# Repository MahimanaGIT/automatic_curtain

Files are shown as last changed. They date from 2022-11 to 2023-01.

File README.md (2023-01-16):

<h1 align="center">Automatic Curtain</h1>

<div align="center">
Elevate your home with IoT-enabled smart curtain controller for effortless living
</div>

## ⭐️ Why Automatic Curtain?
Automating blinds can provide convenience and energy efficiency. They can be programmed to open and close at specific times of the day, allowing natural light in to reduce the need of artificial lighting. They can also be controlled remotely, making it easy to adjust the amount of light and privacy in a room without having to physically adjust the blinds. Additionally, automatic blinds can help to regulate the temperature in a room.

## 🔥 Watch the video

<p align="center">
  <a href="https://www.youtube.com/watch?v=RMJ6SqKFGqU">
    Video
  </a>
</p>

## ✨ Features

- 😎 Easy to set up and integrate
- 📱 Remote control - the ability to open and close the curtains with precision using Alexa app
- 🛡 Safety feature - the ability to detect obstacles and stop the motor to prevent injury or damage to the curtains
- 💅 Manual Override - the ability to manually operate the curtains in case of Alexa not available
- 🚀 Motorized operation - the ability to open and close the curtains using a motor, rather than manual operation
- 📦 Smart home integration - the ability to connect the blinds to other smart home devices such as thermostat using alexa. Provides added convenience and energy efficiency

## 📋 [Doxygen Documentation](https://mahimanagit.github.io/automatic_curtain/)

## 🚀 Getting Started
### For how to use and build your own, refer [🗒 Manual](resources/MANUAL/manual.pdf)
### 👨‍💻 [Coding Style](https://google.github.io/styleguide/cppguide.html)
### Steps to setup for development:
1. Clone the repo
2. Setup clang format:
   - Install clang format extension in VS Code: 
    ```
      Name: Clang-Format
      Id: xaver.clang-format
      Description: Use Clang-Format in Visual Studio Code
      Version: 1.9.0
      Publisher: xaver
      VS Marketplace Link: https://marketplace.visualstudio.com/items?itemName=xaver.clang-format
    ```
   - Add following lines to **settings.json** in your VS Code:
    ```
    "editor.formatOnSave": true
    ```
    Now, everytime you save your code will automatically be formatted according to clang
    
3. Setup ESP32 Arduino Core using [this guide](https://randomnerdtutorials.com/installing-the-esp32-board-in-arduino-ide-windows-instructions/)
   
4. Setup Libraries
   - The link to all the libraries can be found at the end of this page. A compressed folder of all the libraries can be found in the [folder](resources/LIBRARY_ZIP/ac_lib.zip)
   - You can download the libraries using the links or just copy the extracted libraries from the above compressed folder in the **~/Arduino/libraries** or your customized library folder.

### Optional setup for development:
1. Setup doxygen:
   - Install doxygen and graphviz (doxygen uses dot from graphviz to generate graphs):
      ```
      sudo apt-get install doxygen
      sudo apt-get install graphviz 
      ```
   - Currently, the **DOT_PATH** is hardcoded in **Doxyfile** as `/usr/bin/dot` on line no. 2398, one can check if the dot path in their system is same or not by running
      ```
      which dot
      ```
      If the path is different, update it in the doxyfile
   - Generate doxygen files by running the following command in the terminal:
      ```
      doxygen Doxyfile
      ```
    - The files will be available in `doxygen` folder, click on or open `index.html` in **html** folder with any browser and you would be able to browse the documentation

## 🛡️ License

Automatic Curtain is licensed under the MIT License - see the [LICENSE](LICENSE.md) file for details.

## 🗒 References:

Thanks to the following repos for making the journey easier for the project:

1. [AsyncTCP](https://github.com/me-no-dev/AsyncTCP.git)
2. [Fauxmo](https://github.com/vintlabs/fauxmoESP.git)
3. [ESPAsyncWebServer](https://github.com/me-no-dev/ESPAsyncWebServer.git)
4. [FastLED](https://github.com/FastLED/FastLED.git)
5. [TMCStepper](https://github.com/teemuatlut/TMCStepper.gi)

For awesome readme help, referenced [novu](https://github.com/novuhq/novu)

## ✏️ Contributors 

- Dhiraj Deshmukh (deshmukhdhiraj15@gmail.com)
- Mahimana Bhatt (mahimanabhatt@gmail.com)

## 💻 Need Help?

We are more than happy to help you. If you are getting any errors or facing problems while working on this project, join our [slack](https://join.slack.com/t/mad-myj2315/shared_invite/zt-1n3oqsv1z-pdAomyv074gVCvfYfFaRgA) and ask for help. We are open to discussing anything related to the project.

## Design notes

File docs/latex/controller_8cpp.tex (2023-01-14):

\hypertarget{controller_8cpp}{}\section{mvp/src/controller/controller.cpp File Reference}
\label{controller_8cpp}\index{mvp/src/controller/controller.\+cpp@{mvp/src/controller/controller.\+cpp}}

Contains algorithms which controls the whole device from initialization to giving commands to every subsystem.  

{\ttfamily \#include \char`\"{}controller.\+h\char`\"{}}\newline
{\ttfamily \#include $<$Arduino.\+h$>$}\newline
{\ttfamily \#include $<$stdio.\+h$>$}\newline
{\ttfamily \#include $<$stdlib.\+h$>$}\newline
{\ttfamily \#include $<$chrono$>$}\newline
{\ttfamily \#include $<$memory$>$}\newline
{\ttfamily \#include \char`\"{}../alexa\+\_\+interaction/alexa\+\_\+interaction.\+h\char`\"{}}\newline
{\ttfamily \#include \char`\"{}../config/config.\+h\char`\"{}}\newline
{\ttfamily \#include \char`\"{}../connectivity/connectivity.\+h\char`\"{}}\newline
{\ttfamily \#include \char`\"{}../indicator/indicator.\+h\char`\"{}}\newline
{\ttfamily \#include \char`\"{}../logging/logging.\+h\char`\"{}}\newline
{\ttfamily \#include \char`\"{}../manual\+\_\+interaction/manual\+\_\+interaction.\+h\char`\"{}}\newline
{\ttfamily \#include \char`\"{}../motor\+\_\+driver/motor\+\_\+driver.\+h\char`\"{}}\newline
{\ttfamily \#include \char`\"{}../storage/storage.\+h\char`\"{}}\newline
Include dependency graph for controller.\+cpp\+:
\nopagebreak
\begin{figure}[H]
\begin{center}
\leavevmode
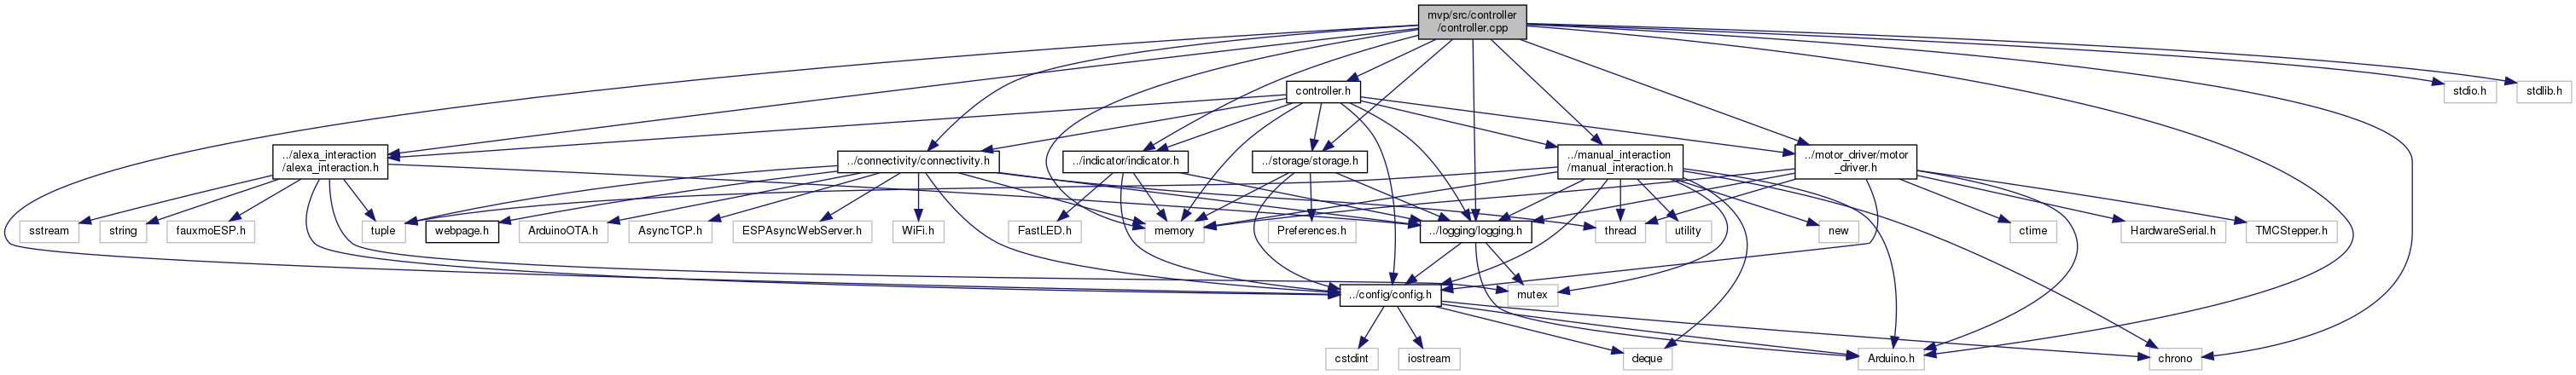
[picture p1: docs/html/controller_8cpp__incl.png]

\end{center}
\end{figure}

\subsection{Detailed Description}
Contains algorithms which controls the whole device from initialization to giving commands to every subsystem. 

\begin{DoxyAuthor}{Author}
Dhiraj Deshmukh (\href{mailto:deshmukhdhiraj15@gmail.com}{\tt deshmukhdhiraj15@gmail.\+com}) 
\end{DoxyAuthor}
\begin{DoxyVersion}{Version}
0.\+1 
\end{DoxyVersion}
\begin{DoxyDate}{Date}
2022-\/07-\/19
\end{DoxyDate}
\begin{DoxyCopyright}{Copyright}
Copyright (c) 2022 
\end{DoxyCopyright}

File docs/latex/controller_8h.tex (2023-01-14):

\hypertarget{controller_8h}{}\section{mvp/src/controller/controller.h File Reference}
\label{controller_8h}\index{mvp/src/controller/controller.\+h@{mvp/src/controller/controller.\+h}}

Defines the structure of the main controller of the device.  

{\ttfamily \#include $<$memory$>$}\newline
{\ttfamily \#include \char`\"{}../alexa\+\_\+interaction/alexa\+\_\+interaction.\+h\char`\"{}}\newline
{\ttfamily \#include \char`\"{}../config/config.\+h\char`\"{}}\newline
{\ttfamily \#include \char`\"{}../connectivity/connectivity.\+h\char`\"{}}\newline
{\ttfamily \#include \char`\"{}../indicator/indicator.\+h\char`\"{}}\newline
{\ttfamily \#include \char`\"{}../logging/logging.\+h\char`\"{}}\newline
{\ttfamily \#include \char`\"{}../manual\+\_\+interaction/manual\+\_\+interaction.\+h\char`\"{}}\newline
{\ttfamily \#include \char`\"{}../motor\+\_\+driver/motor\+\_\+driver.\+h\char`\"{}}\newline
{\ttfamily \#include \char`\"{}../storage/storage.\+h\char`\"{}}\newline
Include dependency graph for controller.\+h\+:
\nopagebreak
\begin{figure}[H]
\begin{center}
\leavevmode
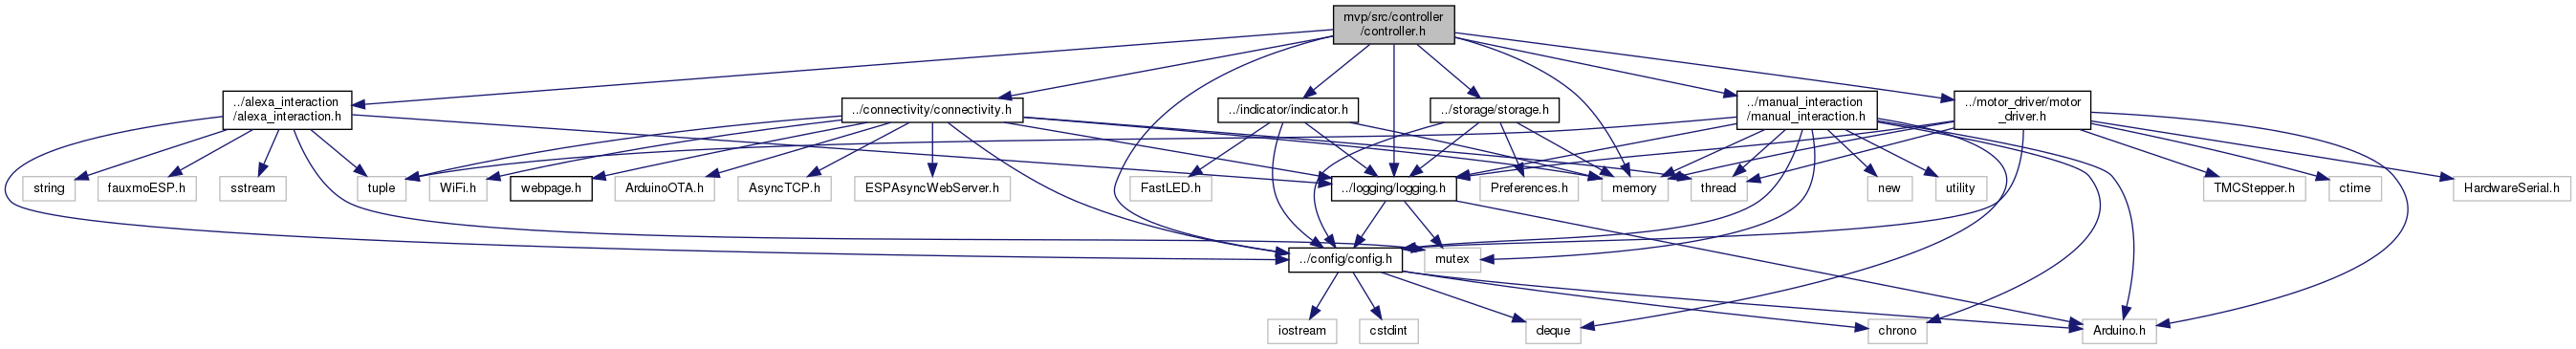
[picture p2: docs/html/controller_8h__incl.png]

\end{center}
\end{figure}
This graph shows which files directly or indirectly include this file\+:
\nopagebreak
\begin{figure}[H]
\begin{center}
\leavevmode
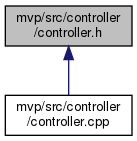
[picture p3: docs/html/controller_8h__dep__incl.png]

\end{center}
\end{figure}
\subsection*{Classes}
\begin{DoxyCompactItemize}
\item 
class \hyperlink{classController}{Controller}
\end{DoxyCompactItemize}

\subsection{Detailed Description}
Defines the structure of the main controller of the device. 

\begin{DoxyAuthor}{Author}
Mahimana Bhatt (\href{mailto:mahimanabhatt@gmail.com}{\tt mahimanabhatt@gmail.\+com}) 
\end{DoxyAuthor}
\begin{DoxyVersion}{Version}
0.\+1 
\end{DoxyVersion}
\begin{DoxyDate}{Date}
2022-\/07-\/19
\end{DoxyDate}
\begin{DoxyCopyright}{Copyright}
Copyright (c) 2022 
\end{DoxyCopyright}

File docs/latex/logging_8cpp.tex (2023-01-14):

\hypertarget{logging_8cpp}{}\section{mvp/src/logging/logging.cpp File Reference}
\label{logging_8cpp}\index{mvp/src/logging/logging.\+cpp@{mvp/src/logging/logging.\+cpp}}

Contains all algorithms for maintaing device logs.  

{\ttfamily \#include \char`\"{}logging.\+h\char`\"{}}\newline
{\ttfamily \#include $<$Arduino.\+h$>$}\newline
{\ttfamily \#include $<$mutex$>$}\newline
{\ttfamily \#include \char`\"{}../config/config.\+h\char`\"{}}\newline
Include dependency graph for logging.\+cpp\+:
\nopagebreak
\begin{figure}[H]
\begin{center}
\leavevmode
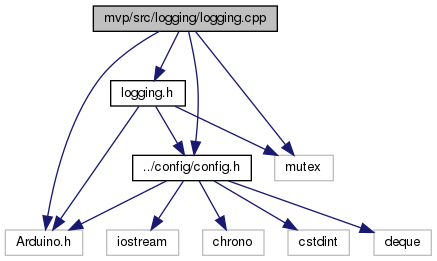
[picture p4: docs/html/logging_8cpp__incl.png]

\end{center}
\end{figure}

\subsection{Detailed Description}
Contains all algorithms for maintaing device logs. 

\begin{DoxyAuthor}{Author}
Dhiraj Deshmukh (\href{mailto:deshmukhdhiraj15@gmail.com}{\tt deshmukhdhiraj15@gmail.\+com}) 
\end{DoxyAuthor}
\begin{DoxyVersion}{Version}
0.\+1 
\end{DoxyVersion}
\begin{DoxyDate}{Date}
2022-\/07-\/19
\end{DoxyDate}
\begin{DoxyCopyright}{Copyright}
Copyright (c) 2022 
\end{DoxyCopyright}

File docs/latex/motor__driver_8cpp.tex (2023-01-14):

\hypertarget{motor__driver_8cpp}{}\section{mvp/src/motor\+\_\+driver/motor\+\_\+driver.cpp File Reference}
\label{motor__driver_8cpp}\index{mvp/src/motor\+\_\+driver/motor\+\_\+driver.\+cpp@{mvp/src/motor\+\_\+driver/motor\+\_\+driver.\+cpp}}

Contains algorithms for controlling stepper motor.  

{\ttfamily \#include \char`\"{}motor\+\_\+driver.\+h\char`\"{}}\newline
{\ttfamily \#include $<$Arduino.\+h$>$}\newline
{\ttfamily \#include $<$Hardware\+Serial.\+h$>$}\newline
{\ttfamily \#include $<$T\+M\+C\+Stepper.\+h$>$}\newline
{\ttfamily \#include $<$ctime$>$}\newline
{\ttfamily \#include \char`\"{}../config/config.\+h\char`\"{}}\newline
{\ttfamily \#include \char`\"{}../logging/logging.\+h\char`\"{}}\newline
Include dependency graph for motor\+\_\+driver.\+cpp\+:
\nopagebreak
\begin{figure}[H]
\begin{center}
\leavevmode
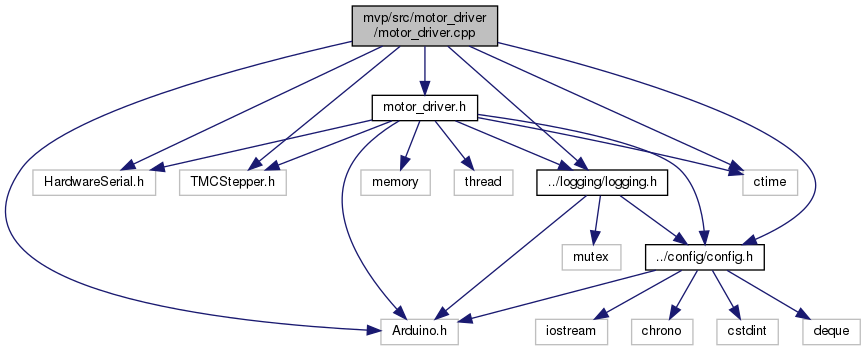
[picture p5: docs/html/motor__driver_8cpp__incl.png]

\end{center}
\end{figure}

\subsection{Detailed Description}
Contains algorithms for controlling stepper motor. 

\begin{DoxyAuthor}{Author}
Dhiraj Deshmukh (\href{mailto:deshmukhdhiraj15@gmail.com}{\tt deshmukhdhiraj15@gmail.\+com}) 
\end{DoxyAuthor}
\begin{DoxyVersion}{Version}
0.\+1 
\end{DoxyVersion}
\begin{DoxyDate}{Date}
2022-\/07-\/19
\end{DoxyDate}
\begin{DoxyCopyright}{Copyright}
Copyright (c) 2022 
\end{DoxyCopyright}

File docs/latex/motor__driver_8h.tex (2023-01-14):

\hypertarget{motor__driver_8h}{}\section{mvp/src/motor\+\_\+driver/motor\+\_\+driver.h File Reference}
\label{motor__driver_8h}\index{mvp/src/motor\+\_\+driver/motor\+\_\+driver.\+h@{mvp/src/motor\+\_\+driver/motor\+\_\+driver.\+h}}

Defines structure for controller of stepper motor, uses library T\+M\+C2209 for this usecase.  

{\ttfamily \#include $<$Arduino.\+h$>$}\newline
{\ttfamily \#include $<$Hardware\+Serial.\+h$>$}\newline
{\ttfamily \#include $<$T\+M\+C\+Stepper.\+h$>$}\newline
{\ttfamily \#include $<$ctime$>$}\newline
{\ttfamily \#include $<$memory$>$}\newline
{\ttfamily \#include $<$thread$>$}\newline
{\ttfamily \#include \char`\"{}../config/config.\+h\char`\"{}}\newline
{\ttfamily \#include \char`\"{}../logging/logging.\+h\char`\"{}}\newline
Include dependency graph for motor\+\_\+driver.\+h\+:
\nopagebreak
\begin{figure}[H]
\begin{center}
\leavevmode
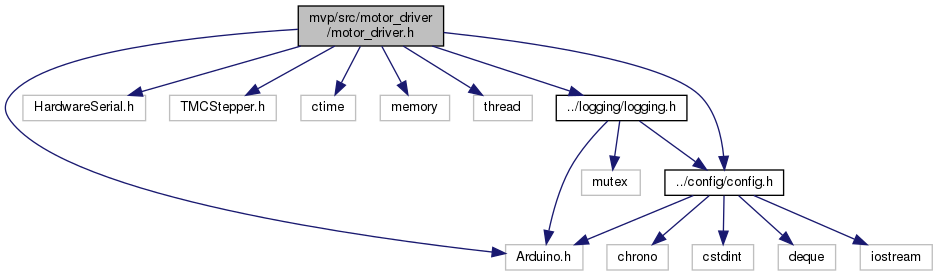
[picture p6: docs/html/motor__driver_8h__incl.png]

\end{center}
\end{figure}
This graph shows which files directly or indirectly include this file\+:
\nopagebreak
\begin{figure}[H]
\begin{center}
\leavevmode
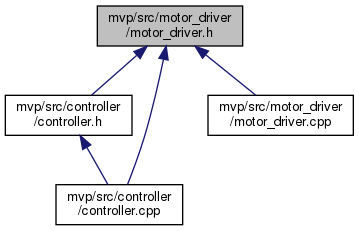
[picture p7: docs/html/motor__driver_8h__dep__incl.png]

\end{center}
\end{figure}
\subsection*{Classes}
\begin{DoxyCompactItemize}
\item 
class \hyperlink{classMotorDriver}{Motor\+Driver}
\end{DoxyCompactItemize}

\subsection{Detailed Description}
Defines structure for controller of stepper motor, uses library T\+M\+C2209 for this usecase. 

\begin{DoxyAuthor}{Author}
Mahimana Bhatt (\href{mailto:mahimanabhatt@gmail.com}{\tt mahimanabhatt@gmail.\+com}) \mbox{[}F\+U\+T\+U\+RE\mbox{]} Do all motor driver control using serial comm, replacing the step and dir pins
\end{DoxyAuthor}
\begin{DoxyVersion}{Version}
0.\+1 
\end{DoxyVersion}
\begin{DoxyDate}{Date}
2022-\/07-\/19
\end{DoxyDate}
\begin{DoxyCopyright}{Copyright}
Copyright (c) 2022 
\end{DoxyCopyright}

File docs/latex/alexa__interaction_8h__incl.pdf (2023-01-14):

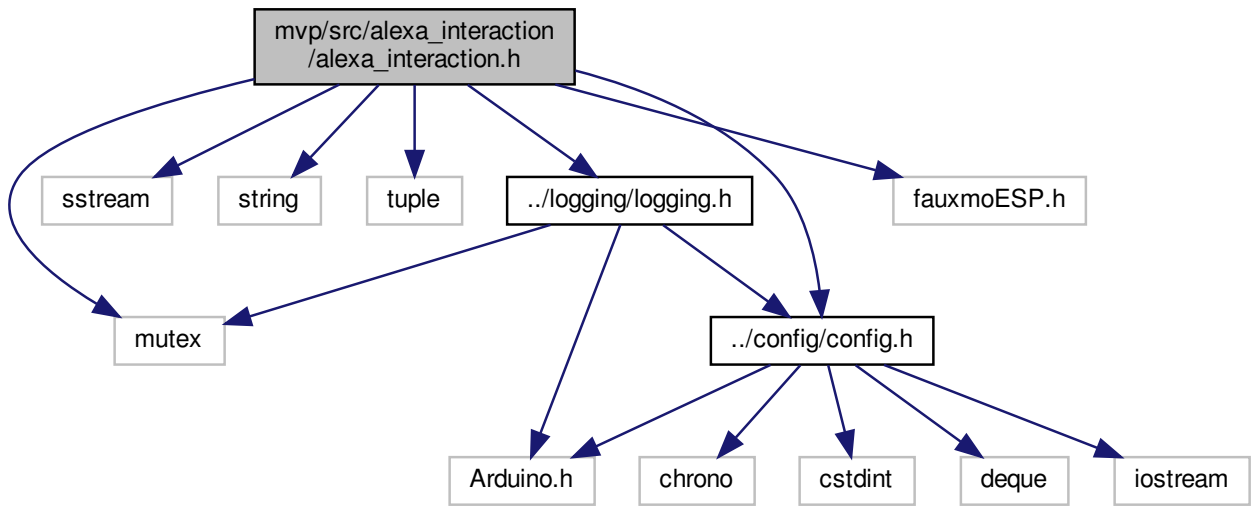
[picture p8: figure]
mvp/src/alexa_interaction /alexa_interaction.h; mutex; sstream; string; tuple; ../config/config.h; ../logging/logging.h; fauxmoESP.h; Arduino.h; chrono; cstdint; deque; iostream

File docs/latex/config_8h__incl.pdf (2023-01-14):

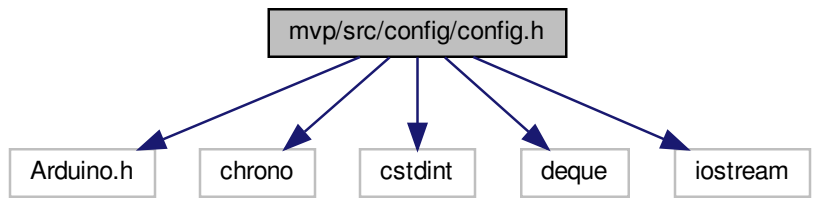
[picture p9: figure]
mvp/src/config/config.h; Arduino.h; chrono; cstdint; deque; iostream

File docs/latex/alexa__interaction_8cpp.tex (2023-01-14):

\hypertarget{alexa__interaction_8cpp}{}\section{mvp/src/alexa\+\_\+interaction/alexa\+\_\+interaction.cpp File Reference}
\label{alexa__interaction_8cpp}\index{mvp/src/alexa\+\_\+interaction/alexa\+\_\+interaction.\+cpp@{mvp/src/alexa\+\_\+interaction/alexa\+\_\+interaction.\+cpp}}

Contains algorithms for handling alexa requests and make appropriate call at every request.  

{\ttfamily \#include \char`\"{}alexa\+\_\+interaction.\+h\char`\"{}}\newline
{\ttfamily \#include $<$mutex$>$}\newline
{\ttfamily \#include $<$string$>$}\newline
{\ttfamily \#include $<$tuple$>$}\newline
{\ttfamily \#include \char`\"{}../config/config.\+h\char`\"{}}\newline
{\ttfamily \#include \char`\"{}../logging/logging.\+h\char`\"{}}\newline
{\ttfamily \#include \char`\"{}fauxmo\+E\+S\+P.\+h\char`\"{}}\newline
Include dependency graph for alexa\+\_\+interaction.\+cpp\+:
\nopagebreak
\begin{figure}[H]
\begin{center}
\leavevmode
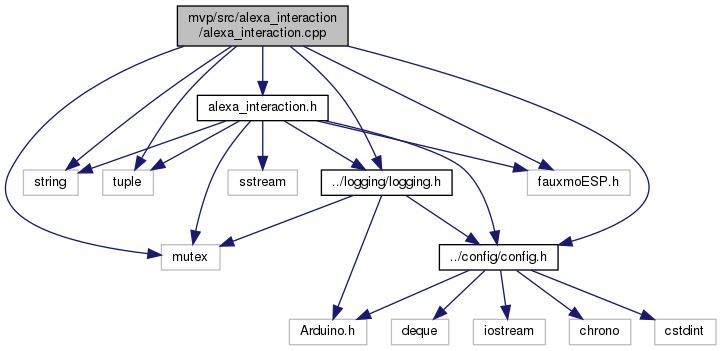
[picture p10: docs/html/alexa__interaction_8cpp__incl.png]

\end{center}
\end{figure}

\subsection{Detailed Description}
Contains algorithms for handling alexa requests and make appropriate call at every request. 

\begin{DoxyAuthor}{Author}
Dhiraj Deshmukh (\href{mailto:deshmukhdhiraj15@gmail.com}{\tt deshmukhdhiraj15@gmail.\+com}) 
\end{DoxyAuthor}
\begin{DoxyVersion}{Version}
0.\+1 
\end{DoxyVersion}
\begin{DoxyDate}{Date}
2022-\/07-\/20
\end{DoxyDate}
\begin{DoxyCopyright}{Copyright}
Copyright (c) 2022 
\end{DoxyCopyright}

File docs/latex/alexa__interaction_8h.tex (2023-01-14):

\hypertarget{alexa__interaction_8h}{}\section{mvp/src/alexa\+\_\+interaction/alexa\+\_\+interaction.h File Reference}
\label{alexa__interaction_8h}\index{mvp/src/alexa\+\_\+interaction/alexa\+\_\+interaction.\+h@{mvp/src/alexa\+\_\+interaction/alexa\+\_\+interaction.\+h}}

Defines structure for class which will be interacting with alexa A\+PI.  

{\ttfamily \#include $<$mutex$>$}\newline
{\ttfamily \#include $<$sstream$>$}\newline
{\ttfamily \#include $<$string$>$}\newline
{\ttfamily \#include $<$tuple$>$}\newline
{\ttfamily \#include \char`\"{}../config/config.\+h\char`\"{}}\newline
{\ttfamily \#include \char`\"{}../logging/logging.\+h\char`\"{}}\newline
{\ttfamily \#include \char`\"{}fauxmo\+E\+S\+P.\+h\char`\"{}}\newline
Include dependency graph for alexa\+\_\+interaction.\+h\+:
\nopagebreak
\begin{figure}[H]
\begin{center}
\leavevmode

\end{center}
\end{figure}
This graph shows which files directly or indirectly include this file\+:
\nopagebreak
\begin{figure}[H]
\begin{center}
\leavevmode
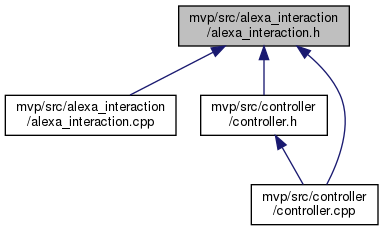
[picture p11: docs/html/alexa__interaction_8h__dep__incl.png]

\end{center}
\end{figure}
\subsection*{Classes}
\begin{DoxyCompactItemize}
\item 
class \hyperlink{classAlexaInteraction}{Alexa\+Interaction}
\end{DoxyCompactItemize}

\subsection{Detailed Description}
Defines structure for class which will be interacting with alexa A\+PI. 

\begin{DoxyAuthor}{Author}
Mahimana Bhatt (\href{mailto:mahimanabhatt@gmail.com}{\tt mahimanabhatt@gmail.\+com}) 
\end{DoxyAuthor}
\begin{DoxyVersion}{Version}
0.\+1 
\end{DoxyVersion}
\begin{DoxyDate}{Date}
2022-\/07-\/20
\end{DoxyDate}
\begin{DoxyCopyright}{Copyright}
Copyright (c) 2022 
\end{DoxyCopyright}

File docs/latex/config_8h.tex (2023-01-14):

\hypertarget{config_8h}{}\section{mvp/src/config/config.h File Reference}
\label{config_8h}\index{mvp/src/config/config.\+h@{mvp/src/config/config.\+h}}

This header file contains all the constants and enum that will be used throughout the repository like specific pins, mapping from state to led color etc.  

{\ttfamily \#include $<$Arduino.\+h$>$}\newline
{\ttfamily \#include $<$chrono$>$}\newline
{\ttfamily \#include $<$cstdint$>$}\newline
{\ttfamily \#include $<$deque$>$}\newline
{\ttfamily \#include $<$iostream$>$}\newline
Include dependency graph for config.\+h\+:
\nopagebreak
\begin{figure}[H]
\begin{center}
\leavevmode

\end{center}
\end{figure}
This graph shows which files directly or indirectly include this file\+:
\nopagebreak
\begin{figure}[H]
\begin{center}
\leavevmode
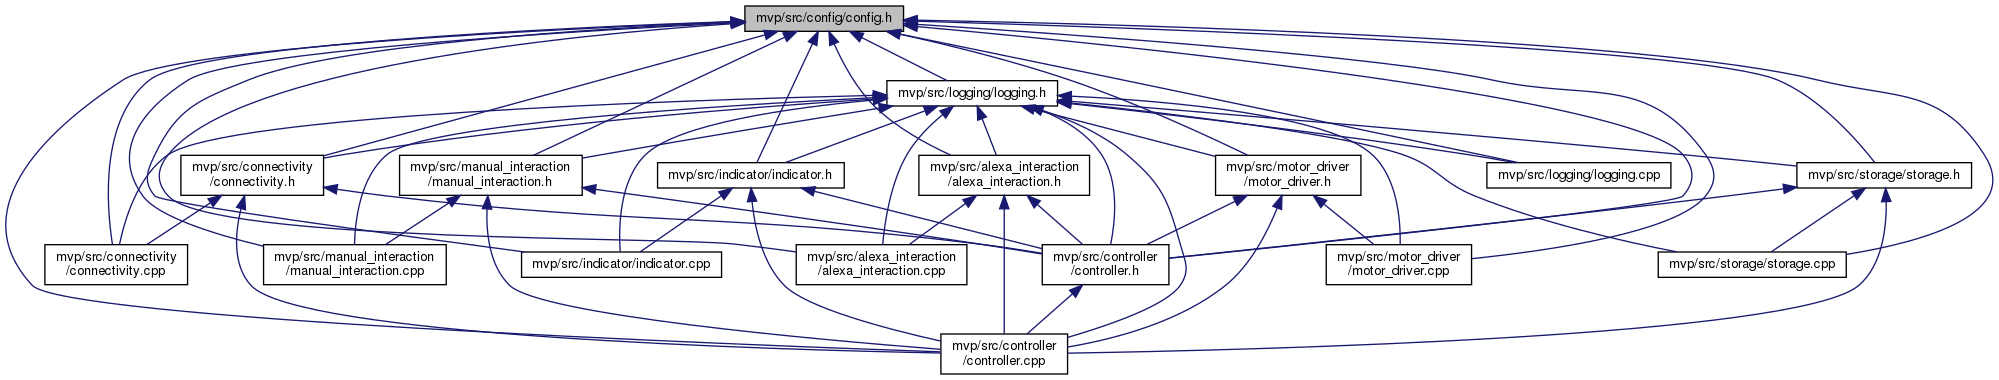
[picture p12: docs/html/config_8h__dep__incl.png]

\end{center}
\end{figure}
\subsection*{Classes}
\begin{DoxyCompactItemize}
\item 
struct \hyperlink{structCONFIG__SET_1_1MOTION__REQUEST}{C\+O\+N\+F\+I\+G\+\_\+\+S\+E\+T\+::\+M\+O\+T\+I\+O\+N\+\_\+\+R\+E\+Q\+U\+E\+ST}
\item 
struct \hyperlink{structCONFIG__SET_1_1DEVICE__CRED}{C\+O\+N\+F\+I\+G\+\_\+\+S\+E\+T\+::\+D\+E\+V\+I\+C\+E\+\_\+\+C\+R\+ED}
\item 
struct \hyperlink{structCONFIG__SET_1_1CALIB__PARAMS}{C\+O\+N\+F\+I\+G\+\_\+\+S\+E\+T\+::\+C\+A\+L\+I\+B\+\_\+\+P\+A\+R\+A\+MS}
\end{DoxyCompactItemize}
\subsection*{Namespaces}
\begin{DoxyCompactItemize}
\item 
 \hyperlink{namespaceCONFIG__SET}{C\+O\+N\+F\+I\+G\+\_\+\+S\+ET}
\begin{DoxyCompactList}\small\item\em Namespace to be used for constants/enums. \end{DoxyCompactList}\end{DoxyCompactItemize}
\subsection*{Typedefs}
\begin{DoxyCompactItemize}
\item 
using \hyperlink{namespaceCONFIG__SET_a8816a22e7885d027a52bfa0d24fa9008}{C\+O\+N\+F\+I\+G\+\_\+\+S\+E\+T\+::time\+\_\+var} = std\+::chrono\+::time\+\_\+point$<$ std\+::chrono\+::system\+\_\+clock $>$
\item 
using \hyperlink{namespaceCONFIG__SET_a7a1c6f926aead4885c03f1fbeee693ce}{C\+O\+N\+F\+I\+G\+\_\+\+S\+E\+T\+::current\+\_\+time} = std\+::chrono\+::system\+\_\+clock
\end{DoxyCompactItemize}
\subsection*{Enumerations}
\begin{DoxyCompactItemize}
\item 
enum \hyperlink{namespaceCONFIG__SET_ac5c2592b79bead7e6497c37cddc401e6}{C\+O\+N\+F\+I\+G\+\_\+\+S\+E\+T\+::\+O\+P\+E\+R\+A\+T\+I\+O\+N\+\_\+\+M\+O\+DE} \{ \hyperlink{namespaceCONFIG__SET_ac5c2592b79bead7e6497c37cddc401e6ab5859d8721cfdc0312b2838b9c985bc1}{C\+O\+N\+F\+I\+G\+\_\+\+S\+E\+T\+::\+O\+P\+E\+R\+A\+T\+I\+O\+N\+\_\+\+M\+O\+D\+E\+::\+R\+E\+S\+ET}, 
\hyperlink{namespaceCONFIG__SET_ac5c2592b79bead7e6497c37cddc401e6aa49182544bf417d2e02cae1f35c9c8b8}{C\+O\+N\+F\+I\+G\+\_\+\+S\+E\+T\+::\+O\+P\+E\+R\+A\+T\+I\+O\+N\+\_\+\+M\+O\+D\+E\+::\+M\+A\+I\+N\+T\+E\+N\+A\+N\+CE}, 
\hyperlink{namespaceCONFIG__SET_ac5c2592b79bead7e6497c37cddc401e6a2e40ad879e955201df4dedbf8d479a12}{C\+O\+N\+F\+I\+G\+\_\+\+S\+E\+T\+::\+O\+P\+E\+R\+A\+T\+I\+O\+N\+\_\+\+M\+O\+D\+E\+::\+U\+S\+ER}, 
\hyperlink{namespaceCONFIG__SET_ac5c2592b79bead7e6497c37cddc401e6ad4cd0dabcf4caa22ad92fab40844c786}{C\+O\+N\+F\+I\+G\+\_\+\+S\+E\+T\+::\+O\+P\+E\+R\+A\+T\+I\+O\+N\+\_\+\+M\+O\+D\+E\+::\+NA}
 \}
\item 
enum \hyperlink{namespaceCONFIG__SET_aaf9764960ee214f0eaabd2461e30e932}{C\+O\+N\+F\+I\+G\+\_\+\+S\+E\+T\+::\+L\+O\+G\+\_\+\+T\+Y\+PE} \{ \hyperlink{namespaceCONFIG__SET_aaf9764960ee214f0eaabd2461e30e932a551b723eafd6a31d444fcb2f5920fbd3}{C\+O\+N\+F\+I\+G\+\_\+\+S\+E\+T\+::\+L\+O\+G\+\_\+\+T\+Y\+P\+E\+::\+I\+N\+FO}, 
\hyperlink{namespaceCONFIG__SET_aaf9764960ee214f0eaabd2461e30e932abb1ca97ec761fc37101737ba0aa2e7c5}{C\+O\+N\+F\+I\+G\+\_\+\+S\+E\+T\+::\+L\+O\+G\+\_\+\+T\+Y\+P\+E\+::\+E\+R\+R\+OR}, 
\hyperlink{namespaceCONFIG__SET_aaf9764960ee214f0eaabd2461e30e932a32bd8a1db2275458673903bdb84cb277}{C\+O\+N\+F\+I\+G\+\_\+\+S\+E\+T\+::\+L\+O\+G\+\_\+\+T\+Y\+P\+E\+::\+W\+A\+RN}
 \}
\item 
enum \hyperlink{namespaceCONFIG__SET_a3c4daebec2ea4e9f6affb5b3abbeb863}{C\+O\+N\+F\+I\+G\+\_\+\+S\+E\+T\+::\+L\+O\+G\+\_\+\+C\+L\+A\+SS} \{ \newline
\hyperlink{namespaceCONFIG__SET_a3c4daebec2ea4e9f6affb5b3abbeb863a42e074e8564dad9034ef033c6a6cf8b6}{C\+O\+N\+F\+I\+G\+\_\+\+S\+E\+T\+::\+L\+O\+G\+\_\+\+C\+L\+A\+S\+S\+::\+C\+O\+N\+T\+R\+O\+L\+L\+ER}, 
\hyperlink{namespaceCONFIG__SET_a3c4daebec2ea4e9f6affb5b3abbeb863afe45874d234b693c3648a37d604b0865}{C\+O\+N\+F\+I\+G\+\_\+\+S\+E\+T\+::\+L\+O\+G\+\_\+\+C\+L\+A\+S\+S\+::\+C\+O\+N\+N\+E\+C\+T\+I\+V\+I\+TY}, 
\hyperlink{namespaceCONFIG__SET_a3c4daebec2ea4e9f6affb5b3abbeb863a2b254b1e77ef0d4fe30639ee576bf05d}{C\+O\+N\+F\+I\+G\+\_\+\+S\+E\+T\+::\+L\+O\+G\+\_\+\+C\+L\+A\+S\+S\+::\+I\+N\+D\+I\+C\+A\+T\+OR}, 
\hyperlink{namespaceCONFIG__SET_a3c4daebec2ea4e9f6affb5b3abbeb863a042bca9f4ffd4cb8530fa2a9035e00c3}{C\+O\+N\+F\+I\+G\+\_\+\+S\+E\+T\+::\+L\+O\+G\+\_\+\+C\+L\+A\+S\+S\+::\+L\+O\+G\+G\+I\+NG}, 
\newline
\hyperlink{namespaceCONFIG__SET_a3c4daebec2ea4e9f6affb5b3abbeb863a0b83d32b63ae6ca0805d471c407c39a8}{C\+O\+N\+F\+I\+G\+\_\+\+S\+E\+T\+::\+L\+O\+G\+\_\+\+C\+L\+A\+S\+S\+::\+M\+A\+N\+U\+A\+L\+\_\+\+I\+N\+T\+E\+R\+A\+C\+T\+I\+ON}, 
\hyperlink{namespaceCONFIG__SET_a3c4daebec2ea4e9f6affb5b3abbeb863aef2f278882c5090b495fea73f0f14150}{C\+O\+N\+F\+I\+G\+\_\+\+S\+E\+T\+::\+L\+O\+G\+\_\+\+C\+L\+A\+S\+S\+::\+M\+O\+T\+O\+R\+\_\+\+D\+R\+I\+V\+ER}, 
\hyperlink{namespaceCONFIG__SET_a3c4daebec2ea4e9f6affb5b3abbeb863a754a5d433173b5ddc7debc2110ac575f}{C\+O\+N\+F\+I\+G\+\_\+\+S\+E\+T\+::\+L\+O\+G\+\_\+\+C\+L\+A\+S\+S\+::\+S\+T\+O\+R\+A\+GE}, 
\hyperlink{namespaceCONFIG__SET_a3c4daebec2ea4e9f6affb5b3abbeb863ad42bdb2009ad11a7ac3dd12ca97e81da}{C\+O\+N\+F\+I\+G\+\_\+\+S\+E\+T\+::\+L\+O\+G\+\_\+\+C\+L\+A\+S\+S\+::\+A\+L\+E\+X\+A\+\_\+\+I\+N\+T\+E\+R\+A\+C\+T\+I\+ON}
 \}
\item 
enum \hyperlink{namespaceCONFIG__SET_a627706be626fd4e58c539ed120c27748}{C\+O\+N\+F\+I\+G\+\_\+\+S\+E\+T\+::\+M\+A\+N\+U\+A\+L\+\_\+\+P\+U\+SH} \{ \newline
\hyperlink{namespaceCONFIG__SET_a627706be626fd4e58c539ed120c27748a201be4da83bb4099ea70c0fa017f69d5}{C\+O\+N\+F\+I\+G\+\_\+\+S\+E\+T\+::\+M\+A\+N\+U\+A\+L\+\_\+\+P\+U\+S\+H\+::\+N\+O\+\_\+\+P\+U\+SH}, 
\hyperlink{namespaceCONFIG__SET_a627706be626fd4e58c539ed120c27748a452fd0059d3faa302e1e7b98eb0b1e81}{C\+O\+N\+F\+I\+G\+\_\+\+S\+E\+T\+::\+M\+A\+N\+U\+A\+L\+\_\+\+P\+U\+S\+H\+::\+L\+O\+N\+G\+\_\+\+P\+R\+E\+S\+S\+\_\+\+UP}, 
\hyperlink{namespaceCONFIG__SET_a627706be626fd4e58c539ed120c27748aab27af1260dbe253aac03e395b9b23ff}{C\+O\+N\+F\+I\+G\+\_\+\+S\+E\+T\+::\+M\+A\+N\+U\+A\+L\+\_\+\+P\+U\+S\+H\+::\+L\+O\+N\+G\+\_\+\+P\+R\+E\+S\+S\+\_\+\+D\+O\+WN}, 
\hyperlink{namespaceCONFIG__SET_a627706be626fd4e58c539ed120c27748a88803b906ab3fb49d793794cccc85713}{C\+O\+N\+F\+I\+G\+\_\+\+S\+E\+T\+::\+M\+A\+N\+U\+A\+L\+\_\+\+P\+U\+S\+H\+::\+L\+O\+N\+G\+\_\+\+P\+R\+E\+S\+S\+\_\+\+B\+O\+TH}, 
\newline
\hyperlink{namespaceCONFIG__SET_a627706be626fd4e58c539ed120c27748ab985c91c3413dee3833c52f7587927d4}{C\+O\+N\+F\+I\+G\+\_\+\+S\+E\+T\+::\+M\+A\+N\+U\+A\+L\+\_\+\+P\+U\+S\+H\+::\+D\+O\+U\+B\+L\+E\+\_\+\+T\+A\+P\+\_\+\+UP}, 
\hyperlink{namespaceCONFIG__SET_a627706be626fd4e58c539ed120c27748a344b76ee59e91ead4475cd148aba681f}{C\+O\+N\+F\+I\+G\+\_\+\+S\+E\+T\+::\+M\+A\+N\+U\+A\+L\+\_\+\+P\+U\+S\+H\+::\+D\+O\+U\+B\+L\+E\+\_\+\+T\+A\+P\+\_\+\+D\+O\+WN}, 
\hyperlink{namespaceCONFIG__SET_a627706be626fd4e58c539ed120c27748ab6e371bad37f26516750c7661c68f491}{C\+O\+N\+F\+I\+G\+\_\+\+S\+E\+T\+::\+M\+A\+N\+U\+A\+L\+\_\+\+P\+U\+S\+H\+::\+D\+O\+U\+B\+L\+E\+\_\+\+T\+A\+P\+\_\+\+B\+O\+TH}
 \}
\item 
enum \hyperlink{namespaceCONFIG__SET_a94751f576b4a29d791e7871295c48b72}{C\+O\+N\+F\+I\+G\+\_\+\+S\+E\+T\+::\+B\+U\+T\+T\+O\+N\+\_\+\+P\+R\+E\+SS} \{ \hyperlink{namespaceCONFIG__SET_a94751f576b4a29d791e7871295c48b72a201be4da83bb4099ea70c0fa017f69d5}{C\+O\+N\+F\+I\+G\+\_\+\+S\+E\+T\+::\+B\+U\+T\+T\+O\+N\+\_\+\+P\+R\+E\+S\+S\+::\+N\+O\+\_\+\+P\+U\+SH}, 
\hyperlink{namespaceCONFIG__SET_a94751f576b4a29d791e7871295c48b72a6cfd612b64bbe4bd62ea3eacec312f2a}{C\+O\+N\+F\+I\+G\+\_\+\+S\+E\+T\+::\+B\+U\+T\+T\+O\+N\+\_\+\+P\+R\+E\+S\+S\+::\+L\+O\+N\+G\+\_\+\+P\+R\+E\+SS}, 
\hyperlink{namespaceCONFIG__SET_a94751f576b4a29d791e7871295c48b72a69262b7d2d5f239bbdeff40c30d17662}{C\+O\+N\+F\+I\+G\+\_\+\+S\+E\+T\+::\+B\+U\+T\+T\+O\+N\+\_\+\+P\+R\+E\+S\+S\+::\+D\+O\+U\+B\+L\+E\+\_\+\+T\+AP}
 \}
\item 
enum \hyperlink{namespaceCONFIG__SET_a8379cbe9f81ee38829b156f47261081a}{C\+O\+N\+F\+I\+G\+\_\+\+S\+E\+T\+::\+D\+E\+V\+I\+C\+E\+\_\+\+S\+T\+A\+T\+US} \{ \hyperlink{namespaceCONFIG__SET_a8379cbe9f81ee38829b156f47261081aa893b3aaf1661e3717b18e8335ff93a72}{C\+O\+N\+F\+I\+G\+\_\+\+S\+E\+T\+::\+D\+E\+V\+I\+C\+E\+\_\+\+S\+T\+A\+T\+U\+S\+::\+F\+A\+U\+LT}, 
\hyperlink{namespaceCONFIG__SET_a8379cbe9f81ee38829b156f47261081aa3fe019c6817599387124ce924e33c70b}{C\+O\+N\+F\+I\+G\+\_\+\+S\+E\+T\+::\+D\+E\+V\+I\+C\+E\+\_\+\+S\+T\+A\+T\+U\+S\+::\+O\+P\+E\+R\+A\+T\+I\+O\+N\+\_\+\+M\+O\+DE}, 
\hyperlink{namespaceCONFIG__SET_a8379cbe9f81ee38829b156f47261081aaba12d2493fc3be7067212035e03a7c04}{C\+O\+N\+F\+I\+G\+\_\+\+S\+E\+T\+::\+D\+E\+V\+I\+C\+E\+\_\+\+S\+T\+A\+T\+U\+S\+::\+R\+E\+S\+E\+T\+\_\+\+M\+O\+DE}, 
\hyperlink{namespaceCONFIG__SET_a8379cbe9f81ee38829b156f47261081aaaf0bd6c96a36aa63de9f0ac59060deea}{C\+O\+N\+F\+I\+G\+\_\+\+S\+E\+T\+::\+D\+E\+V\+I\+C\+E\+\_\+\+S\+T\+A\+T\+U\+S\+::\+M\+A\+I\+N\+T\+E\+N\+A\+N\+C\+E\+\_\+\+M\+O\+DE}
 \}
\item 
enum \hyperlink{namespaceCONFIG__SET_a722f4ba49e35faf1a2504aa23677b2f0}{C\+O\+N\+F\+I\+G\+\_\+\+S\+E\+T\+::\+D\+R\+I\+V\+E\+R\+\_\+\+S\+T\+A\+T\+US} \{ \hyperlink{namespaceCONFIG__SET_a722f4ba49e35faf1a2504aa23677b2f0a1588118736b5ecdb1ac20c16428d8ea7}{C\+O\+N\+F\+I\+G\+\_\+\+S\+E\+T\+::\+D\+R\+I\+V\+E\+R\+\_\+\+S\+T\+A\+T\+U\+S\+::\+A\+V\+A\+I\+L\+A\+B\+LE}, 
\hyperlink{namespaceCONFIG__SET_a722f4ba49e35faf1a2504aa23677b2f0a802706a9238e2928077f97736854bad4}{C\+O\+N\+F\+I\+G\+\_\+\+S\+E\+T\+::\+D\+R\+I\+V\+E\+R\+\_\+\+S\+T\+A\+T\+U\+S\+::\+B\+U\+SY}, 
\hyperlink{namespaceCONFIG__SET_a722f4ba49e35faf1a2504aa23677b2f0a81ec94fc396b06d900dfec53805d1732}{C\+O\+N\+F\+I\+G\+\_\+\+S\+E\+T\+::\+D\+R\+I\+V\+E\+R\+\_\+\+S\+T\+A\+T\+U\+S\+::\+I\+N\+\_\+\+A\+C\+T\+I\+VE}
 \}
\end{DoxyCompactItemize}
\subsection*{Variables}
\begin{DoxyCompactItemize}
\item 
const int \hyperlink{namespaceCONFIG__SET_aa9d9cee85d0c1416ccb5ed5f801de6db}{C\+O\+N\+F\+I\+G\+\_\+\+S\+E\+T\+::\+L\+O\+G\+G\+I\+N\+G\+\_\+\+B\+A\+U\+D\+\_\+\+R\+A\+TE} = 115200
\item 
const int \hyperlink{namespaceCONFIG__SET_a7db23e13f6ec09a9be65fad30733470e}{C\+O\+N\+F\+I\+G\+\_\+\+S\+E\+T\+::\+M\+O\+T\+O\+R\+\_\+\+D\+R\+I\+V\+E\+R\+\_\+\+B\+A\+U\+D\+\_\+\+R\+A\+TE} = 115200
\item 
const int \hyperlink{namespaceCONFIG__SET_a0d526cb827f2f3c5236874a4157448af}{C\+O\+N\+F\+I\+G\+\_\+\+S\+E\+T\+::\+T\+R\+Y\+\_\+\+R\+E\+C\+O\+N\+N\+E\+CT} = 3
\item 
const int \hyperlink{namespaceCONFIG__SET_a4a1488bbde32db8f3d362761adc7c637}{C\+O\+N\+F\+I\+G\+\_\+\+S\+E\+T\+::\+M\+A\+X\+\_\+\+S\+E\+C\+O\+N\+D\+S\+\_\+\+L\+O\+S\+T\+\_\+\+W\+I\+FI} = 600
\item 
const std\+::string \hyperlink{namespaceCONFIG__SET_adc424e5a5b81f2016a88456fd2f383d9}{C\+O\+N\+F\+I\+G\+\_\+\+S\+E\+T\+::\+S\+T\+O\+R\+A\+G\+E\+\_\+\+N\+A\+M\+E\+S\+P\+A\+CE} = \char`\"{}madac\char`\"{}
\item 
const int \hyperlink{namespaceCONFIG__SET_a91d987372150d727ecbb41b39d482911}{C\+O\+N\+F\+I\+G\+\_\+\+S\+E\+T\+::\+N\+U\+M\+B\+E\+R\+\_\+\+O\+F\+\_\+\+L\+E\+DS} = 1
\item 
const int \hyperlink{namespaceCONFIG__SET_ae380133af7dbc440e94dd1d32ca8011c}{C\+O\+N\+F\+I\+G\+\_\+\+S\+E\+T\+::\+L\+E\+D\+\_\+\+B\+R\+I\+G\+H\+T\+N\+E\+SS} = 25
\item 
const int \hyperlink{namespaceCONFIG__SET_af30cde25aaad1a3f7c1056df78fe44ef}{C\+O\+N\+F\+I\+G\+\_\+\+S\+E\+T\+::\+D\+E\+Q\+U\+E\+\_\+\+A\+N\+A\+L\+Y\+Z\+E\+R\+\_\+\+F\+R\+EQ} = 2
\item 
const std\+::string \hyperlink{namespaceCONFIG__SET_adc315222607c5e3c4aa1e0d13b6987ee}{C\+O\+N\+F\+I\+G\+\_\+\+S\+E\+T\+::\+K\+E\+Y\+\_\+\+S\+S\+ID} = \char`\"{}ssid\char`\"{}
\item 
const std\+::string \hyperlink{namespaceCONFIG__SET_a19f24640ed129493b066d05e146deaf3}{C\+O\+N\+F\+I\+G\+\_\+\+S\+E\+T\+::\+K\+E\+Y\+\_\+\+P\+A\+S\+S\+W\+O\+RD} = \char`\"{}password\char`\"{}
\item 
const std\+::string \hyperlink{namespaceCONFIG__SET_af0e474e6061134d6cbf04e0c890552d9}{C\+O\+N\+F\+I\+G\+\_\+\+S\+E\+T\+::\+K\+E\+Y\+\_\+\+D\+E\+V\+I\+C\+E\+\_\+\+ID} = \char`\"{}device\+ID\char`\"{}
\item 
const std\+::string \hyperlink{namespaceCONFIG__SET_acb991fe6c1317a4bf770b8b1a049ad25}{C\+O\+N\+F\+I\+G\+\_\+\+S\+E\+T\+::\+K\+E\+Y\+\_\+\+T\+O\+T\+A\+L\+\_\+\+S\+T\+E\+P\+\_\+\+C\+O\+U\+NT} = \char`\"{}total\+Step\+Count\char`\"{}
\item 
const std\+::string \hyperlink{namespaceCONFIG__SET_a01f506112394a3ac18b3a731a710984c}{C\+O\+N\+F\+I\+G\+\_\+\+S\+E\+T\+::\+K\+E\+Y\+\_\+\+D\+I\+R\+E\+C\+T\+I\+ON} = \char`\"{}direction\char`\"{}
\item 
const std\+::string \hyperlink{namespaceCONFIG__SET_a77febd18d2a2712e1357b057a52e9be3}{C\+O\+N\+F\+I\+G\+\_\+\+S\+E\+T\+::\+K\+E\+Y\+\_\+\+M\+O\+DE} = \char`\"{}mode\char`\"{}
\item 
const String \hyperlink{namespaceCONFIG__SET_a2ac88bd64607d4819d1bda478f469817}{C\+O\+N\+F\+I\+G\+\_\+\+S\+E\+T\+::\+D\+E\+F\+A\+U\+L\+T\+\_\+\+D\+E\+V\+I\+C\+E\+\_\+\+ID} = \char`\"{}madac\+\_\+blinds\char`\"{}
\item 
const float \hyperlink{namespaceCONFIG__SET_a8f23ef59b087dff79c434bd84525a915}{C\+O\+N\+F\+I\+G\+\_\+\+S\+E\+T\+::\+M\+O\+T\+O\+R\+\_\+\+D\+R\+I\+V\+E\+R\+\_\+\+R\+\_\+\+S\+E\+N\+SE} = 0.\+11f
\item 
const uint8\+\_\+t \hyperlink{namespaceCONFIG__SET_a6a76f57577e628d797a633669d8adced}{C\+O\+N\+F\+I\+G\+\_\+\+S\+E\+T\+::\+M\+O\+T\+O\+R\+\_\+\+D\+R\+I\+V\+E\+R\+\_\+\+A\+D\+D\+R\+E\+SS} = 0b00
\item 
const uint8\+\_\+t \hyperlink{namespaceCONFIG__SET_a9cd2f24701a5f7debb61387d734af3f7}{C\+O\+N\+F\+I\+G\+\_\+\+S\+E\+T\+::\+M\+O\+T\+O\+R\+\_\+\+D\+R\+I\+V\+E\+R\+\_\+\+T\+O\+FF} = 4
\item 
const uint8\+\_\+t \hyperlink{namespaceCONFIG__SET_abd06bbb93246b7d98d1e7c2e5e4954b4}{C\+O\+N\+F\+I\+G\+\_\+\+S\+E\+T\+::\+M\+O\+T\+O\+R\+\_\+\+D\+R\+I\+V\+E\+R\+\_\+\+B\+L\+A\+N\+K\+\_\+\+T\+I\+ME} = 24
\item 
const uint16\+\_\+t \hyperlink{namespaceCONFIG__SET_a367788b61bc20c95602dec7063093fce}{C\+O\+N\+F\+I\+G\+\_\+\+S\+E\+T\+::\+M\+O\+T\+O\+R\+\_\+\+D\+R\+I\+V\+E\+R\+\_\+\+R\+M\+S\+\_\+\+C\+U\+R\+R\+E\+NT} = 2000
\item 
const uint16\+\_\+t \hyperlink{namespaceCONFIG__SET_a7028034ed96d5ef10a87d1cdc12c5d27}{C\+O\+N\+F\+I\+G\+\_\+\+S\+E\+T\+::\+M\+O\+T\+O\+R\+\_\+\+D\+R\+I\+V\+E\+R\+\_\+\+M\+I\+C\+R\+O\+S\+T\+EP} = 16
\item 
const uint32\+\_\+t \hyperlink{namespaceCONFIG__SET_aaaf7add03a2bd7b4a1cad95838dc6545}{C\+O\+N\+F\+I\+G\+\_\+\+S\+E\+T\+::\+M\+O\+T\+O\+R\+\_\+\+D\+R\+I\+V\+E\+R\+\_\+\+T\+C\+O\+O\+L\+\_\+\+T\+H\+RS} = 0x\+F\+F\+F\+FF
\item 
const uint8\+\_\+t \hyperlink{namespaceCONFIG__SET_a32dc4d5c8cc5890bf7f9be0a7f15bdb2}{C\+O\+N\+F\+I\+G\+\_\+\+S\+E\+T\+::\+M\+O\+T\+O\+R\+\_\+\+D\+R\+I\+V\+E\+R\+\_\+\+S\+E\+\_\+\+M\+IN} = 0
\item 
const uint8\+\_\+t \hyperlink{namespaceCONFIG__SET_a790b63a59051c9e242aff5b4123a9ca5}{C\+O\+N\+F\+I\+G\+\_\+\+S\+E\+T\+::\+M\+O\+T\+O\+R\+\_\+\+D\+R\+I\+V\+E\+R\+\_\+\+S\+E\+\_\+\+M\+AX} = 2
\item 
const uint8\+\_\+t \hyperlink{namespaceCONFIG__SET_a957a048d0f02b3bca4145248c6d79c77}{C\+O\+N\+F\+I\+G\+\_\+\+S\+E\+T\+::\+M\+O\+T\+O\+R\+\_\+\+D\+R\+I\+V\+E\+R\+\_\+\+S\+E\+DN} = 0b01
\item 
const uint32\+\_\+t \hyperlink{namespaceCONFIG__SET_ad8683609012e266d026138915afb2c4c}{C\+O\+N\+F\+I\+G\+\_\+\+S\+E\+T\+::\+M\+O\+T\+O\+R\+\_\+\+D\+R\+I\+V\+E\+R\+\_\+\+M\+A\+X\+\_\+\+S\+P\+E\+ED} = 5000
\item 
const int \hyperlink{namespaceCONFIG__SET_a56ca50a3b66685f81410683733371590}{C\+O\+N\+F\+I\+G\+\_\+\+S\+E\+T\+::\+M\+O\+T\+O\+R\+\_\+\+D\+R\+I\+V\+E\+R\+\_\+\+S\+G\+\_\+\+T\+H\+R\+E\+SH} = 45
\item 
const int \hyperlink{namespaceCONFIG__SET_a4cfa726833e14a8607e9c4c8b5895792}{C\+O\+N\+F\+I\+G\+\_\+\+S\+E\+T\+::\+M\+O\+T\+O\+R\+\_\+\+S\+T\+O\+P\+\_\+\+T\+I\+M\+E\+\_\+\+S\+EC} = 120
\item 
const float \hyperlink{namespaceCONFIG__SET_ae98d33bba82717c83e577914428d2f87}{C\+O\+N\+F\+I\+G\+\_\+\+S\+E\+T\+::\+S\+T\+E\+P\+\_\+\+F\+R\+A\+C\+T\+I\+O\+N\+\_\+\+A\+L\+L\+O\+W\+A\+N\+CE} = 0.\+05
\item 
const int \hyperlink{namespaceCONFIG__SET_a4e51168ed48d5e6ff6bdd26da8fd0244}{C\+O\+N\+F\+I\+G\+\_\+\+S\+E\+T\+::\+M\+O\+D\+E\+\_\+\+E\+X\+P\+I\+R\+E\+\_\+\+T\+I\+M\+E\+\_\+\+L\+I\+M\+IT} = 300
\item 
const int \hyperlink{namespaceCONFIG__SET_a538190e043ad035b08b9fc653d6a0491}{C\+O\+N\+F\+I\+G\+\_\+\+S\+E\+T\+::\+W\+I\+F\+I\+\_\+\+D\+I\+S\+C\+O\+N\+N\+E\+C\+T\+\_\+\+R\+E\+S\+T\+A\+R\+T\+\_\+\+T\+I\+M\+E\+\_\+\+L\+I\+M\+IT} = 60
\item 
const int \hyperlink{namespaceCONFIG__SET_a932d38d647f5793b7ebb07de5c7baf7b}{C\+O\+N\+F\+I\+G\+\_\+\+S\+E\+T\+::\+P\+I\+N\+\_\+\+R\+G\+B\+\_\+\+L\+ED} = 32
\item 
static const int \hyperlink{namespaceCONFIG__SET_a2a69cb92b89581f4a67d29a1a808327b}{C\+O\+N\+F\+I\+G\+\_\+\+S\+E\+T\+::\+P\+I\+N\+\_\+\+B\+U\+T\+T\+O\+N\+\_\+\+UP} = 33
\item 
static const int \hyperlink{namespaceCONFIG__SET_a5bf40b051395303a194e7afab2a66d43}{C\+O\+N\+F\+I\+G\+\_\+\+S\+E\+T\+::\+P\+I\+N\+\_\+\+B\+U\+T\+T\+O\+N\+\_\+\+D\+O\+WN} = 25
\item 
const int \hyperlink{namespaceCONFIG__SET_a76e1dbd32a24123a8e1c6f1032553e9e}{C\+O\+N\+F\+I\+G\+\_\+\+S\+E\+T\+::\+P\+I\+N\+\_\+\+M\+D\+\_\+\+E\+N\+A\+B\+LE} = 4
\item 
const int \hyperlink{namespaceCONFIG__SET_a3cd5a807c53edf90423ef292df549a2c}{C\+O\+N\+F\+I\+G\+\_\+\+S\+E\+T\+::\+P\+I\+N\+\_\+\+M\+D\+\_\+\+RX} = 16
\item 
const int \hyperlink{namespaceCONFIG__SET_ae14a96410643d22f30b5e7f98bbc2e98}{C\+O\+N\+F\+I\+G\+\_\+\+S\+E\+T\+::\+P\+I\+N\+\_\+\+M\+D\+\_\+\+TX} = 17
\item 
const int \hyperlink{namespaceCONFIG__SET_af93fc82a783571bf68af757e1a59be8d}{C\+O\+N\+F\+I\+G\+\_\+\+S\+E\+T\+::\+P\+I\+N\+\_\+\+M\+D\+\_\+\+M\+S1} = 5
\item 
const int \hyperlink{namespaceCONFIG__SET_a3ae1a9238a4c2ef99018a568fb407188}{C\+O\+N\+F\+I\+G\+\_\+\+S\+E\+T\+::\+P\+I\+N\+\_\+\+M\+D\+\_\+\+M\+S2} = 18
\item 
const int \hyperlink{namespaceCONFIG__SET_a6ff1241febf3c05949aa4e9615126aaa}{C\+O\+N\+F\+I\+G\+\_\+\+S\+E\+T\+::\+P\+I\+N\+\_\+\+M\+D\+\_\+\+S\+T\+EP} = 22
\item 
const int \hyperlink{namespaceCONFIG__SET_a893c9a17e861d557ec6e6d009d02f1fd}{C\+O\+N\+F\+I\+G\+\_\+\+S\+E\+T\+::\+P\+I\+N\+\_\+\+M\+D\+\_\+\+D\+IR} = 23
\item 
const int \hyperlink{namespaceCONFIG__SET_a77c4124103e0be77050f54fed8f46cbe}{C\+O\+N\+F\+I\+G\+\_\+\+S\+E\+T\+::\+P\+I\+N\+\_\+\+M\+D\+\_\+\+I\+N\+D\+EX} = 21
\item 
const int \hyperlink{namespaceCONFIG__SET_a24d0005db5d888efec3ad54d1d21d319}{C\+O\+N\+F\+I\+G\+\_\+\+S\+E\+T\+::\+P\+I\+N\+\_\+\+M\+D\+\_\+\+D\+I\+AG} = 19
\end{DoxyCompactItemize}

\subsection{Detailed Description}
This header file contains all the constants and enum that will be used throughout the repository like specific pins, mapping from state to led color etc. 

\begin{DoxyAuthor}{Author}
Mahimana Bhatt (\href{mailto:mahimanabhatt@gmail.com}{\tt mahimanabhatt@gmail.\+com}) 
\end{DoxyAuthor}
\begin{DoxyVersion}{Version}
0.\+1 
\end{DoxyVersion}
\begin{DoxyDate}{Date}
2022-\/07-\/19
\end{DoxyDate}
\begin{DoxyCopyright}{Copyright}
Copyright (c) 2022 
\end{DoxyCopyright}

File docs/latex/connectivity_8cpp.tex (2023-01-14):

\hypertarget{connectivity_8cpp}{}\section{mvp/src/connectivity/connectivity.cpp File Reference}
\label{connectivity_8cpp}\index{mvp/src/connectivity/connectivity.\+cpp@{mvp/src/connectivity/connectivity.\+cpp}}

Contains algorithms related to connecting to Wi\+Fi, O\+TA updates and webpage display.  

{\ttfamily \#include \char`\"{}connectivity.\+h\char`\"{}}\newline
{\ttfamily \#include $<$Arduino\+O\+T\+A.\+h$>$}\newline
{\ttfamily \#include $<$Async\+T\+C\+P.\+h$>$}\newline
{\ttfamily \#include $<$E\+S\+P\+Async\+Web\+Server.\+h$>$}\newline
{\ttfamily \#include $<$mutex$>$}\newline
{\ttfamily \#include $<$tuple$>$}\newline
{\ttfamily \#include \char`\"{}../config/config.\+h\char`\"{}}\newline
{\ttfamily \#include \char`\"{}../logging/logging.\+h\char`\"{}}\newline
{\ttfamily \#include \char`\"{}Wi\+Fi.\+h\char`\"{}}\newline
{\ttfamily \#include \char`\"{}webpage.\+h\char`\"{}}\newline
Include dependency graph for connectivity.\+cpp\+:
\nopagebreak
\begin{figure}[H]
\begin{center}
\leavevmode
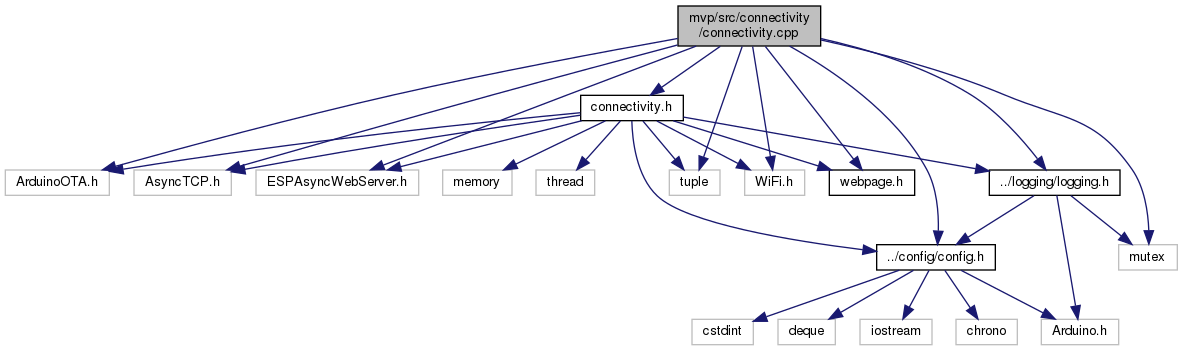
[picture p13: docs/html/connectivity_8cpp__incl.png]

\end{center}
\end{figure}

\subsection{Detailed Description}
Contains algorithms related to connecting to Wi\+Fi, O\+TA updates and webpage display. 

\begin{DoxyAuthor}{Author}
Dhiraj Deshmukh (\href{mailto:deshmukhdhiraj15@gmail.com}{\tt deshmukhdhiraj15@gmail.\+com}) 
\end{DoxyAuthor}
\begin{DoxyVersion}{Version}
0.\+1 
\end{DoxyVersion}
\begin{DoxyDate}{Date}
2022-\/07-\/19
\end{DoxyDate}
\begin{DoxyCopyright}{Copyright}
Copyright (c) 2022 
\end{DoxyCopyright}

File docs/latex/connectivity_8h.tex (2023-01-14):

\hypertarget{connectivity_8h}{}\section{mvp/src/connectivity/connectivity.h File Reference}
\label{connectivity_8h}\index{mvp/src/connectivity/connectivity.\+h@{mvp/src/connectivity/connectivity.\+h}}

Define overall structure for class containing Wi\+Fi, O\+TA and webpage functionality.  

{\ttfamily \#include $<$Arduino\+O\+T\+A.\+h$>$}\newline
{\ttfamily \#include $<$Async\+T\+C\+P.\+h$>$}\newline
{\ttfamily \#include $<$E\+S\+P\+Async\+Web\+Server.\+h$>$}\newline
{\ttfamily \#include $<$memory$>$}\newline
{\ttfamily \#include $<$thread$>$}\newline
{\ttfamily \#include $<$tuple$>$}\newline
{\ttfamily \#include \char`\"{}../config/config.\+h\char`\"{}}\newline
{\ttfamily \#include \char`\"{}../logging/logging.\+h\char`\"{}}\newline
{\ttfamily \#include \char`\"{}Wi\+Fi.\+h\char`\"{}}\newline
{\ttfamily \#include \char`\"{}webpage.\+h\char`\"{}}\newline
Include dependency graph for connectivity.\+h\+:
\nopagebreak
\begin{figure}[H]
\begin{center}
\leavevmode
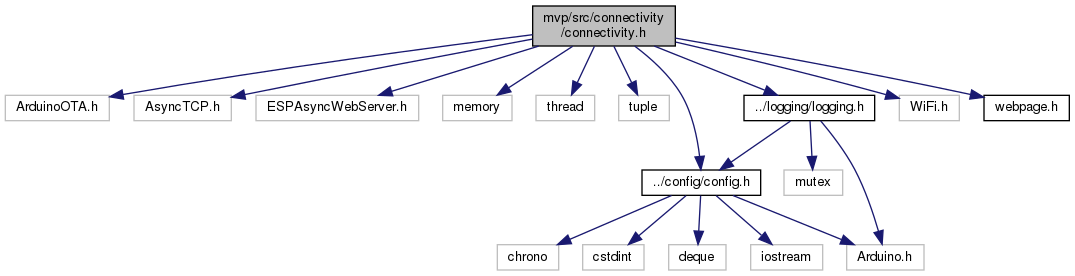
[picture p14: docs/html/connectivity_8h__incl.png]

\end{center}
\end{figure}
This graph shows which files directly or indirectly include this file\+:
\nopagebreak
\begin{figure}[H]
\begin{center}
\leavevmode
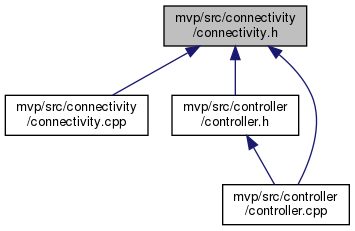
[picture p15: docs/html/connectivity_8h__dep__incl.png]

\end{center}
\end{figure}
\subsection*{Classes}
\begin{DoxyCompactItemize}
\item 
class \hyperlink{classConnectivity}{Connectivity}
\end{DoxyCompactItemize}

\subsection{Detailed Description}
Define overall structure for class containing Wi\+Fi, O\+TA and webpage functionality. 

\begin{DoxyAuthor}{Author}
Mahimana Bhatt (\href{mailto:mahimanabhatt@gmail.com}{\tt mahimanabhatt@gmail.\+com}) 
\end{DoxyAuthor}
\begin{DoxyVersion}{Version}
0.\+1 
\end{DoxyVersion}
\begin{DoxyDate}{Date}
2022-\/07-\/19
\end{DoxyDate}
\begin{DoxyCopyright}{Copyright}
Copyright (c) 2022 
\end{DoxyCopyright}

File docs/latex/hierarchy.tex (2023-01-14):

\section{Class Hierarchy}
This inheritance list is sorted roughly, but not completely, alphabetically\+:\begin{DoxyCompactList}
\item \contentsline{section}{C\+O\+N\+F\+I\+G\+\_\+\+S\+ET\+:\+:C\+A\+L\+I\+B\+\_\+\+P\+A\+R\+A\+MS}{\pageref{structCONFIG__SET_1_1CALIB__PARAMS}}{}
\item \contentsline{section}{Connectivity}{\pageref{classConnectivity}}{}
\item \contentsline{section}{Controller}{\pageref{classController}}{}
\item \contentsline{section}{C\+O\+N\+F\+I\+G\+\_\+\+S\+ET\+:\+:D\+E\+V\+I\+C\+E\+\_\+\+C\+R\+ED}{\pageref{structCONFIG__SET_1_1DEVICE__CRED}}{}
\item fauxmo\+E\+SP\begin{DoxyCompactList}
\item \contentsline{section}{Alexa\+Interaction}{\pageref{classAlexaInteraction}}{}
\end{DoxyCompactList}
\item \contentsline{section}{Indicator}{\pageref{classIndicator}}{}
\item \contentsline{section}{Logging}{\pageref{classLogging}}{}
\item \contentsline{section}{Manual\+Interaction}{\pageref{classManualInteraction}}{}
\item \contentsline{section}{C\+O\+N\+F\+I\+G\+\_\+\+S\+ET\+:\+:M\+O\+T\+I\+O\+N\+\_\+\+R\+E\+Q\+U\+E\+ST}{\pageref{structCONFIG__SET_1_1MOTION__REQUEST}}{}
\item \contentsline{section}{Storage}{\pageref{classStorage}}{}
\item T\+M\+C2209\+Stepper\begin{DoxyCompactList}
\item \contentsline{section}{Motor\+Driver}{\pageref{classMotorDriver}}{}
\end{DoxyCompactList}
\end{DoxyCompactList}

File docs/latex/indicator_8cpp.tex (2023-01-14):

\hypertarget{indicator_8cpp}{}\section{mvp/src/indicator/indicator.cpp File Reference}
\label{indicator_8cpp}\index{mvp/src/indicator/indicator.\+cpp@{mvp/src/indicator/indicator.\+cpp}}

Contains algorithms for R\+GB L\+ED.  

{\ttfamily \#include \char`\"{}indicator.\+h\char`\"{}}\newline
{\ttfamily \#include $<$Fast\+L\+E\+D.\+h$>$}\newline
{\ttfamily \#include \char`\"{}../config/config.\+h\char`\"{}}\newline
{\ttfamily \#include \char`\"{}../logging/logging.\+h\char`\"{}}\newline
Include dependency graph for indicator.\+cpp\+:
\nopagebreak
\begin{figure}[H]
\begin{center}
\leavevmode
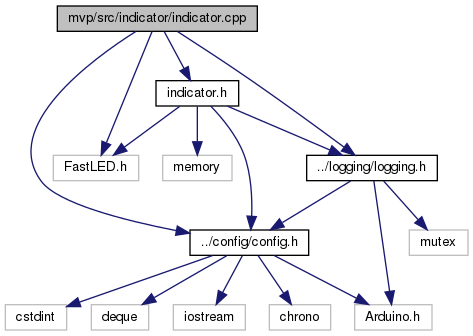
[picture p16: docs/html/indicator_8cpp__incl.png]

\end{center}
\end{figure}

\subsection{Detailed Description}
Contains algorithms for R\+GB L\+ED. 

\begin{DoxyAuthor}{Author}
Dhiraj Deshmukh (\href{mailto:deshmukhdhiraj15@gmail.com}{\tt deshmukhdhiraj15@gmail.\+com}) 
\end{DoxyAuthor}
\begin{DoxyVersion}{Version}
0.\+1 
\end{DoxyVersion}
\begin{DoxyDate}{Date}
2022-\/07-\/19
\end{DoxyDate}
\begin{DoxyCopyright}{Copyright}
Copyright (c) 2022 
\end{DoxyCopyright}

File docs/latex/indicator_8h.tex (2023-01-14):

\hypertarget{indicator_8h}{}\section{mvp/src/indicator/indicator.h File Reference}
\label{indicator_8h}\index{mvp/src/indicator/indicator.\+h@{mvp/src/indicator/indicator.\+h}}

Contains structure for R\+GB L\+ED (C\+OM 11821), uses F\+A\+S\+T\+Led library for controlling the L\+ED.  

{\ttfamily \#include $<$Fast\+L\+E\+D.\+h$>$}\newline
{\ttfamily \#include $<$memory$>$}\newline
{\ttfamily \#include \char`\"{}../config/config.\+h\char`\"{}}\newline
{\ttfamily \#include \char`\"{}../logging/logging.\+h\char`\"{}}\newline
Include dependency graph for indicator.\+h\+:
\nopagebreak
\begin{figure}[H]
\begin{center}
\leavevmode

\end{center}
\end{figure}
This graph shows which files directly or indirectly include this file\+:
\nopagebreak
\begin{figure}[H]
\begin{center}
\leavevmode

\end{center}
\end{figure}
\subsection*{Classes}
\begin{DoxyCompactItemize}
\item 
class \hyperlink{classIndicator}{Indicator}
\end{DoxyCompactItemize}

\subsection{Detailed Description}
Contains structure for R\+GB L\+ED (C\+OM 11821), uses F\+A\+S\+T\+Led library for controlling the L\+ED. 

\begin{DoxyAuthor}{Author}
Mahimana Bhatt (\href{mailto:mahimanabhatt@gmail.com}{\tt mahimanabhatt@gmail.\+com}) 
\end{DoxyAuthor}
\begin{DoxyVersion}{Version}
0.\+1 
\end{DoxyVersion}
\begin{DoxyDate}{Date}
2022-\/07-\/19
\end{DoxyDate}
\begin{DoxyCopyright}{Copyright}
Copyright (c) 2022 
\end{DoxyCopyright}

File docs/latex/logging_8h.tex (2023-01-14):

\hypertarget{logging_8h}{}\section{mvp/src/logging/logging.h File Reference}
\label{logging_8h}\index{mvp/src/logging/logging.\+h@{mvp/src/logging/logging.\+h}}

Defines code structure for logging of device.  

{\ttfamily \#include $<$Arduino.\+h$>$}\newline
{\ttfamily \#include $<$mutex$>$}\newline
{\ttfamily \#include \char`\"{}../config/config.\+h\char`\"{}}\newline
Include dependency graph for logging.\+h\+:
\nopagebreak
\begin{figure}[H]
\begin{center}
\leavevmode
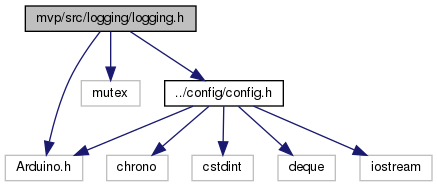
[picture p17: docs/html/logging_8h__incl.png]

\end{center}
\end{figure}
This graph shows which files directly or indirectly include this file\+:
\nopagebreak
\begin{figure}[H]
\begin{center}
\leavevmode
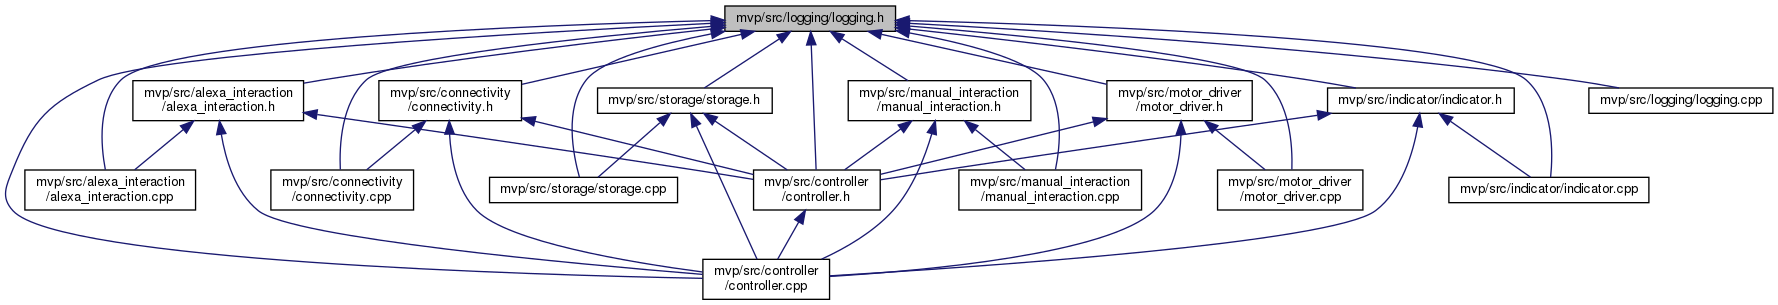
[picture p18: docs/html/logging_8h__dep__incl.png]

\end{center}
\end{figure}
\subsection*{Classes}
\begin{DoxyCompactItemize}
\item 
class \hyperlink{classLogging}{Logging}
\end{DoxyCompactItemize}

\subsection{Detailed Description}
Defines code structure for logging of device. 

\begin{DoxyAuthor}{Author}
Mahimana Bhatt (\href{mailto:mahimanabhatt@gmail.com}{\tt mahimanabhatt@gmail.\+com}) 
\end{DoxyAuthor}
\begin{DoxyVersion}{Version}
0.\+1 
\end{DoxyVersion}
\begin{DoxyDate}{Date}
2022-\/07-\/19
\end{DoxyDate}
\begin{DoxyCopyright}{Copyright}
Copyright (c) 2022 
\end{DoxyCopyright}

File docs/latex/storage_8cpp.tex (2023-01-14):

\hypertarget{storage_8cpp}{}\section{mvp/src/storage/storage.cpp File Reference}
\label{storage_8cpp}\index{mvp/src/storage/storage.\+cpp@{mvp/src/storage/storage.\+cpp}}

Contains algorithms to read and write appropriate device data to Flash.  

{\ttfamily \#include \char`\"{}storage.\+h\char`\"{}}\newline
{\ttfamily \#include $<$Preferences.\+h$>$}\newline
{\ttfamily \#include \char`\"{}../config/config.\+h\char`\"{}}\newline
{\ttfamily \#include \char`\"{}../logging/logging.\+h\char`\"{}}\newline
Include dependency graph for storage.\+cpp\+:
\nopagebreak
\begin{figure}[H]
\begin{center}
\leavevmode
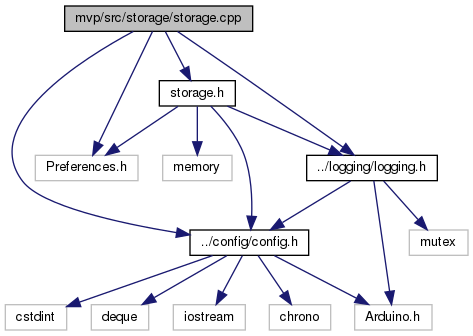
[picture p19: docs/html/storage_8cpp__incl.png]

\end{center}
\end{figure}

\subsection{Detailed Description}
Contains algorithms to read and write appropriate device data to Flash. 

\begin{DoxyAuthor}{Author}
Dhiraj Deshmukh (\href{mailto:deshmukhdhiraj15@gmail.com}{\tt deshmukhdhiraj15@gmail.\+com}) 
\end{DoxyAuthor}
\begin{DoxyVersion}{Version}
0.\+1 
\end{DoxyVersion}
\begin{DoxyDate}{Date}
2022-\/07-\/19
\end{DoxyDate}
\begin{DoxyCopyright}{Copyright}
Copyright (c) 2022 
\end{DoxyCopyright}

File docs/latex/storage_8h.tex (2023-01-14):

\hypertarget{storage_8h}{}\section{mvp/src/storage/storage.h File Reference}
\label{storage_8h}\index{mvp/src/storage/storage.\+h@{mvp/src/storage/storage.\+h}}

Defines structure for Flash storage for E\+S\+P32.  

{\ttfamily \#include $<$Preferences.\+h$>$}\newline
{\ttfamily \#include $<$memory$>$}\newline
{\ttfamily \#include \char`\"{}../config/config.\+h\char`\"{}}\newline
{\ttfamily \#include \char`\"{}../logging/logging.\+h\char`\"{}}\newline
Include dependency graph for storage.\+h\+:
\nopagebreak
\begin{figure}[H]
\begin{center}
\leavevmode
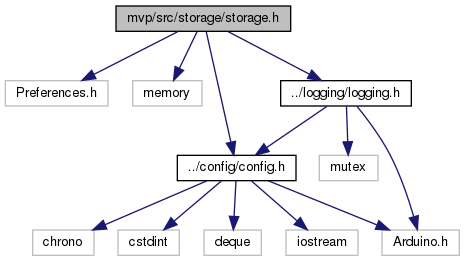
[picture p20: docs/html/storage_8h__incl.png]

\end{center}
\end{figure}
This graph shows which files directly or indirectly include this file\+:
\nopagebreak
\begin{figure}[H]
\begin{center}
\leavevmode
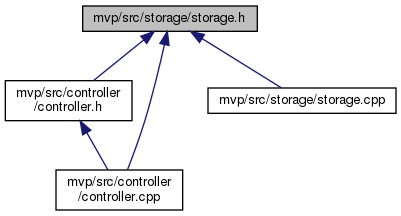
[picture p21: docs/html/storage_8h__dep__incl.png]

\end{center}
\end{figure}
\subsection*{Classes}
\begin{DoxyCompactItemize}
\item 
class \hyperlink{classStorage}{Storage}
\end{DoxyCompactItemize}

\subsection{Detailed Description}
Defines structure for Flash storage for E\+S\+P32. 

\begin{DoxyAuthor}{Author}
Mahimana Bhatt (\href{mailto:mahimanabhatt@gmail.com}{\tt mahimanabhatt@gmail.\+com}) 
\end{DoxyAuthor}
\begin{DoxyVersion}{Version}
0.\+1 
\end{DoxyVersion}
\begin{DoxyDate}{Date}
2022-\/07-\/19
\end{DoxyDate}
\begin{DoxyCopyright}{Copyright}
Copyright (c) 2022 
\end{DoxyCopyright}

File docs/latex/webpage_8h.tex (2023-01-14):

\hypertarget{webpage_8h}{}\section{mvp/src/connectivity/webpage.h File Reference}
\label{webpage_8h}\index{mvp/src/connectivity/webpage.\+h@{mvp/src/connectivity/webpage.\+h}}

Contains resources related to webpage for eg. html code.  

This graph shows which files directly or indirectly include this file\+:
\nopagebreak
\begin{figure}[H]
\begin{center}
\leavevmode
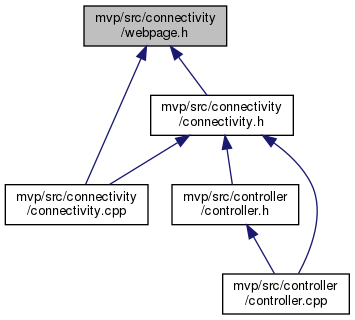
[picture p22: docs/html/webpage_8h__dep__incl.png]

\end{center}
\end{figure}
\subsection*{Variables}
\begin{DoxyCompactItemize}
\item 
const char index\+\_\+html \mbox{[}$\,$\mbox{]} \hyperlink{webpage_8h_a628220fceb5982bf7726339d2b2ebddf}{P\+R\+O\+G\+M\+EM}
\end{DoxyCompactItemize}

\subsection{Detailed Description}
Contains resources related to webpage for eg. html code. 

\begin{DoxyAuthor}{Author}
Mahimana Bhatt (\href{mailto:mahimanabhatt@gmail.com}{\tt mahimanabhatt@gmail.\+com}) 
\end{DoxyAuthor}
\begin{DoxyVersion}{Version}
0.\+1 
\end{DoxyVersion}
\begin{DoxyDate}{Date}
2022-\/07-\/19
\end{DoxyDate}
\begin{DoxyCopyright}{Copyright}
Copyright (c) 2022 
\end{DoxyCopyright}

\subsection{Variable Documentation}
\mbox{\Hypertarget{webpage_8h_a628220fceb5982bf7726339d2b2ebddf}\label{webpage_8h_a628220fceb5982bf7726339d2b2ebddf}} 
\index{webpage.\+h@{webpage.\+h}!P\+R\+O\+G\+M\+EM@{P\+R\+O\+G\+M\+EM}}
\index{P\+R\+O\+G\+M\+EM@{P\+R\+O\+G\+M\+EM}!webpage.\+h@{webpage.\+h}}
\subsubsection{\texorpdfstring{P\+R\+O\+G\+M\+EM}{PROGMEM}}
{\footnotesize\ttfamily const char dialog\+\_\+html \mbox{[}$\,$\mbox{]} P\+R\+O\+G\+M\+EM}

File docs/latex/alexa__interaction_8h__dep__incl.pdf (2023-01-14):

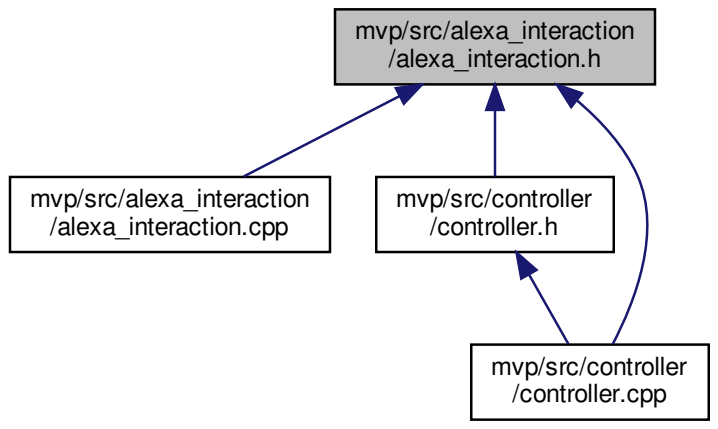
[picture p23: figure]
mvp/src/alexa_interaction /alexa_interaction.h; mvp/src/alexa_interaction /alexa_interaction.cpp; mvp/src/controller /controller.h; mvp/src/controller /controller.cpp

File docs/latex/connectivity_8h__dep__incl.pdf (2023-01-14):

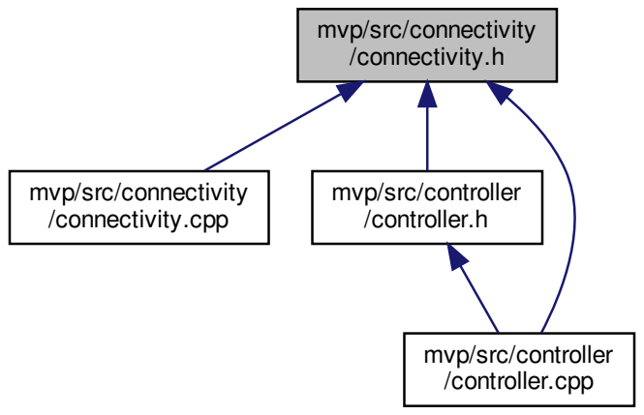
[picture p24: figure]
mvp/src/connectivity /connectivity.h; mvp/src/connectivity /connectivity.cpp; mvp/src/controller /controller.h; mvp/src/controller /controller.cpp

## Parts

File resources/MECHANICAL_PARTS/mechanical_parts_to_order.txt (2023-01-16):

Part                          Link to order
Spacers                       https://a.co/d/f1DOGHC  
Screw nut set                 https://a.co/d/1ob83sX
Motor                         https://a.co/d/7eh5STP
Pulley with timing belt       https://a.co/d/8xv70HU
Shaft                         https://a.co/d/aSR0vuN

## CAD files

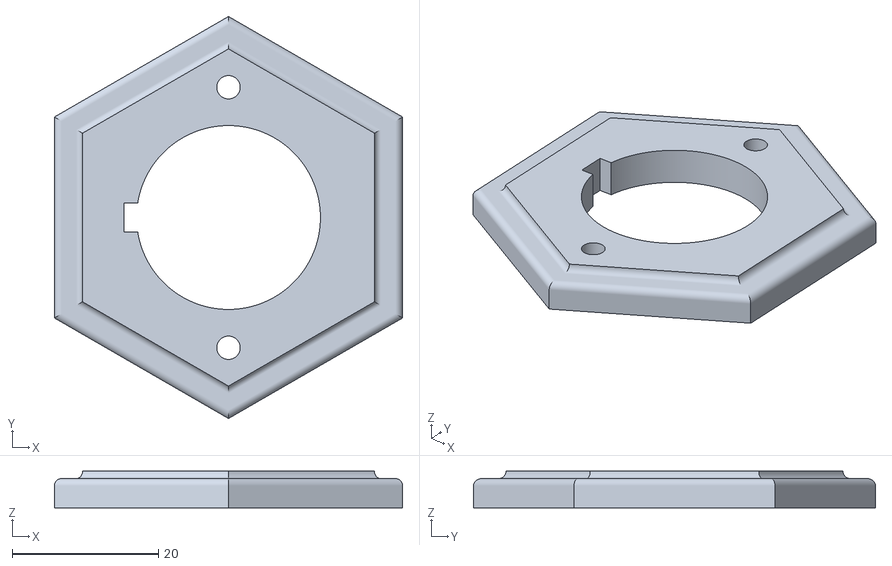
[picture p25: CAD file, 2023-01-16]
resources/MECHANICAL_PARTS/P1_or_P2.STL
47.6 x 55.0 x 5.00

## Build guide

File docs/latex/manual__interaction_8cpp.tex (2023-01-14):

\hypertarget{manual__interaction_8cpp}{}\section{mvp/src/manual\+\_\+interaction/manual\+\_\+interaction.cpp File Reference}
\label{manual__interaction_8cpp}\index{mvp/src/manual\+\_\+interaction/manual\+\_\+interaction.\+cpp@{mvp/src/manual\+\_\+interaction/manual\+\_\+interaction.\+cpp}}

Contains algorithms to detect a users manual interaction with the device, specifically push buttons.  

{\ttfamily \#include \char`\"{}manual\+\_\+interaction.\+h\char`\"{}}\newline
{\ttfamily \#include $<$Arduino.\+h$>$}\newline
{\ttfamily \#include $<$chrono$>$}\newline
{\ttfamily \#include $<$deque$>$}\newline
{\ttfamily \#include $<$memory$>$}\newline
{\ttfamily \#include $<$mutex$>$}\newline
{\ttfamily \#include $<$new$>$}\newline
{\ttfamily \#include $<$tuple$>$}\newline
{\ttfamily \#include $<$utility$>$}\newline
{\ttfamily \#include \char`\"{}../config/config.\+h\char`\"{}}\newline
{\ttfamily \#include \char`\"{}../logging/logging.\+h\char`\"{}}\newline
Include dependency graph for manual\+\_\+interaction.\+cpp\+:
\nopagebreak
\begin{figure}[H]
\begin{center}
\leavevmode
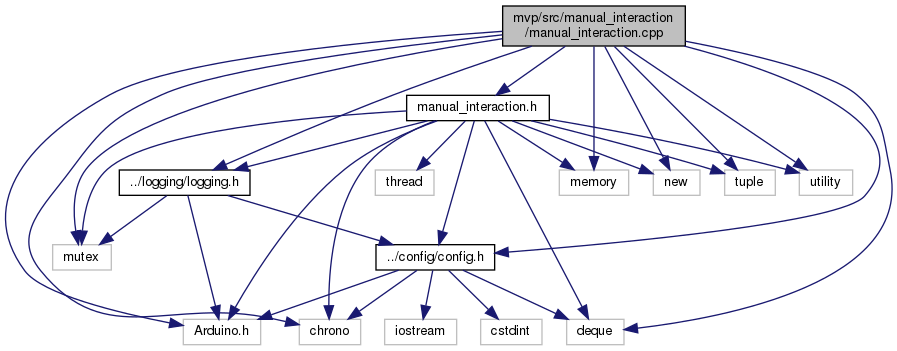
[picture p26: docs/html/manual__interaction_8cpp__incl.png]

\end{center}
\end{figure}

\subsection{Detailed Description}
Contains algorithms to detect a users manual interaction with the device, specifically push buttons. 

\begin{DoxyAuthor}{Author}
Dhiraj Deshmukh (\href{mailto:deshmukhdhiraj15@gmail.com}{\tt deshmukhdhiraj15@gmail.\+com}) 
\end{DoxyAuthor}
\begin{DoxyVersion}{Version}
0.\+1 
\end{DoxyVersion}
\begin{DoxyDate}{Date}
2022-\/07-\/19
\end{DoxyDate}
\begin{DoxyCopyright}{Copyright}
Copyright (c) 2022 
\end{DoxyCopyright}

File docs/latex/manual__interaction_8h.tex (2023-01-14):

\hypertarget{manual__interaction_8h}{}\section{mvp/src/manual\+\_\+interaction/manual\+\_\+interaction.h File Reference}
\label{manual__interaction_8h}\index{mvp/src/manual\+\_\+interaction/manual\+\_\+interaction.\+h@{mvp/src/manual\+\_\+interaction/manual\+\_\+interaction.\+h}}

Defines structure for manual interaction with device.  

{\ttfamily \#include $<$Arduino.\+h$>$}\newline
{\ttfamily \#include $<$chrono$>$}\newline
{\ttfamily \#include $<$deque$>$}\newline
{\ttfamily \#include $<$memory$>$}\newline
{\ttfamily \#include $<$mutex$>$}\newline
{\ttfamily \#include $<$new$>$}\newline
{\ttfamily \#include $<$thread$>$}\newline
{\ttfamily \#include $<$tuple$>$}\newline
{\ttfamily \#include $<$utility$>$}\newline
{\ttfamily \#include \char`\"{}../config/config.\+h\char`\"{}}\newline
{\ttfamily \#include \char`\"{}../logging/logging.\+h\char`\"{}}\newline
Include dependency graph for manual\+\_\+interaction.\+h\+:
\nopagebreak
\begin{figure}[H]
\begin{center}
\leavevmode
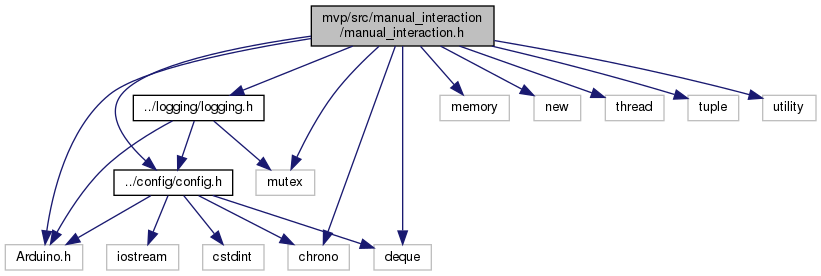
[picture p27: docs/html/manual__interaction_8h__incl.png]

\end{center}
\end{figure}
This graph shows which files directly or indirectly include this file\+:
\nopagebreak
\begin{figure}[H]
\begin{center}
\leavevmode
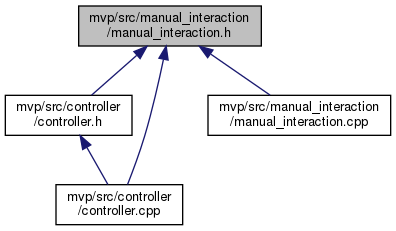
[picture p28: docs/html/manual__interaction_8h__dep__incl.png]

\end{center}
\end{figure}
\subsection*{Classes}
\begin{DoxyCompactItemize}
\item 
class \hyperlink{classManualInteraction}{Manual\+Interaction}
\end{DoxyCompactItemize}

\subsection{Detailed Description}
Defines structure for manual interaction with device. 

\begin{DoxyAuthor}{Author}
Mahimana Bhatt (\href{mailto:mahimanabhatt@gmail.com}{\tt mahimanabhatt@gmail.\+com}) 
\end{DoxyAuthor}
\begin{DoxyVersion}{Version}
0.\+1 
\end{DoxyVersion}
\begin{DoxyDate}{Date}
2022-\/07-\/19
\end{DoxyDate}
\begin{DoxyCopyright}{Copyright}
Copyright (c) 2022 
\end{DoxyCopyright}

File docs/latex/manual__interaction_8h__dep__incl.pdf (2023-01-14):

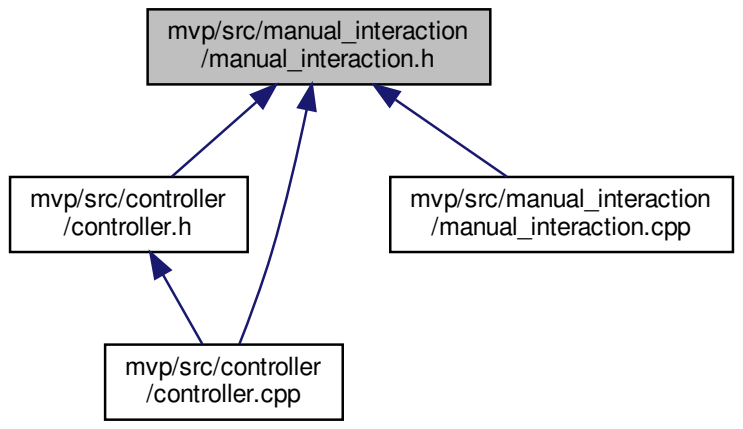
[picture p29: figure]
mvp/src/manual_interaction /manual_interaction.h; mvp/src/controller /controller.h; mvp/src/controller /controller.cpp; mvp/src/manual_interaction /manual_interaction.cpp

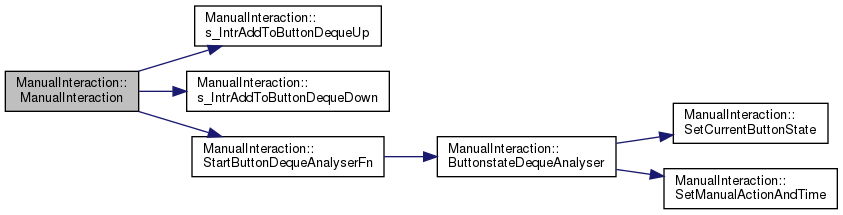
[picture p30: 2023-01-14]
docs/classManualInteraction_a6cad93bd00e4954a8eedacf590038f68_cgraph.png

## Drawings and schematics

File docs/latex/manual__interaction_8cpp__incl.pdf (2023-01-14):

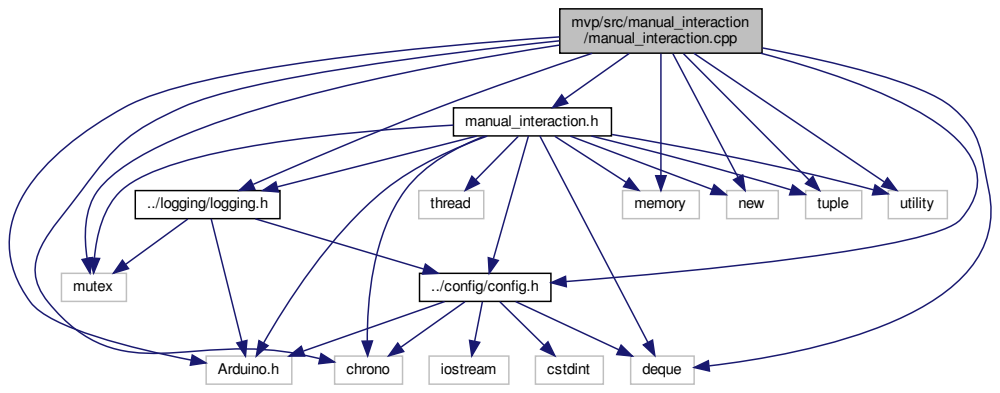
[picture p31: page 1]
mvp/src/manual_interaction /manual_interaction.cpp; manual_interaction.h; Arduino.h; chrono; deque; memory; mutex; new; tuple; utility; ../config/config.h; ../logging/logging.h; thread; iostream; cstdint

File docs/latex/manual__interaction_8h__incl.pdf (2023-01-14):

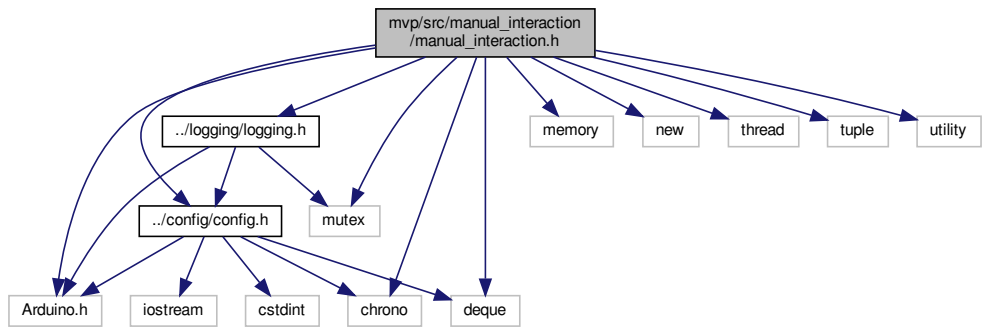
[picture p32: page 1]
mvp/src/manual_interaction /manual_interaction.h; Arduino.h; chrono; deque; memory; mutex; new; thread; tuple; utility; ../config/config.h; ../logging/logging.h; iostream; cstdint

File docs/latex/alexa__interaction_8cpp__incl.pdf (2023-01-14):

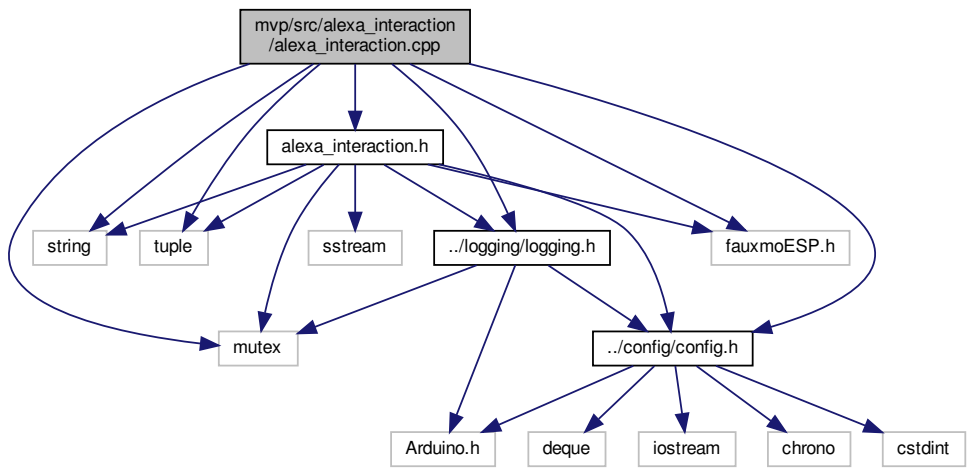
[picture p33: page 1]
mvp/src/alexa_interaction /alexa_interaction.cpp; alexa_interaction.h; mutex; string; tuple; ../config/config.h; sstream; ../logging/logging.h; fauxmoESP.h; Arduino.h; deque; iostream; chrono; cstdint

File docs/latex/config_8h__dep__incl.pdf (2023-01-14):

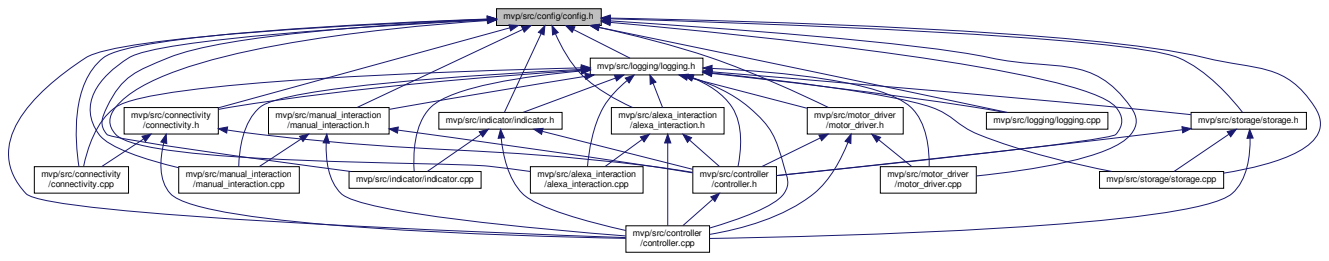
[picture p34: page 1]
mvp/src/alexa_interaction /alexa_interaction.h; mvp/src/alexa_interaction /alexa_interaction.cpp; mvp/src/manual_interaction /manual_interaction.h; mvp/src/manual_interaction /manual_interaction.cpp; mvp/src/motor_driver /motor_driver.h; mvp/src/motor_driver /motor_driver.cpp

mvp/src/config/config.h

mvp/src/logging/logging.h

mvp/src/connectivity
/connectivity.h

mvp/src/indicator/indicator.h

mvp/src/logging/logging.cpp

mvp/src/storage/storage.h

/connectivity.cpp

mvp/src/indicator/indicator.cpp

mvp/src/controller
/controller.h

mvp/src/storage/storage.cpp

/controller.cpp

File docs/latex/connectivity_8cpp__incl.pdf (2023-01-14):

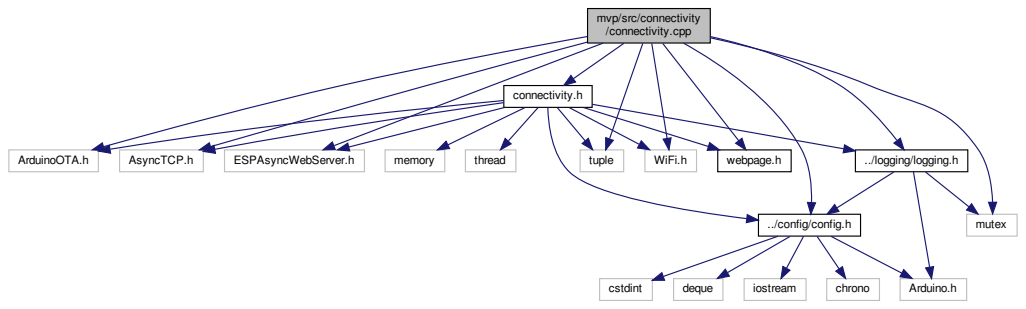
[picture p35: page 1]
connectivity.h; ArduinoOTA.h; AsyncTCP.h; ESPAsyncWebServer.h; tuple; ../config/config.h; ../logging/logging.h; mutex; memory; thread; WiFi.h; webpage.h; cstdint; deque; iostream; chrono; Arduino.h

mvp/src/connectivity
/connectivity.cpp

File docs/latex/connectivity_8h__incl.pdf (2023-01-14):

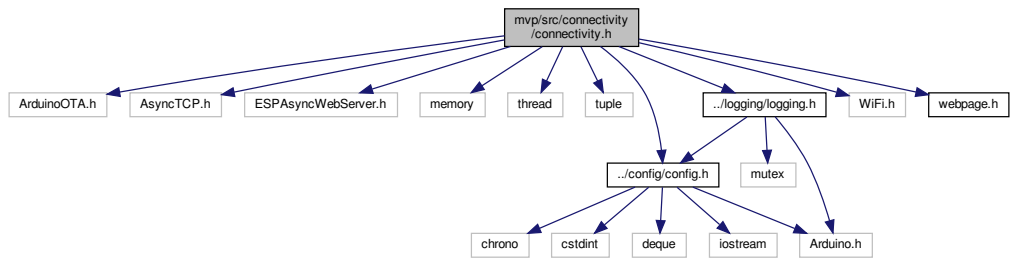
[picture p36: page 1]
ArduinoOTA.h; AsyncTCP.h; ESPAsyncWebServer.h; memory; thread; tuple; ../config/config.h; ../logging/logging.h; WiFi.h; webpage.h; chrono; cstdint; deque; iostream; Arduino.h; mutex

mvp/src/connectivity
/connectivity.h

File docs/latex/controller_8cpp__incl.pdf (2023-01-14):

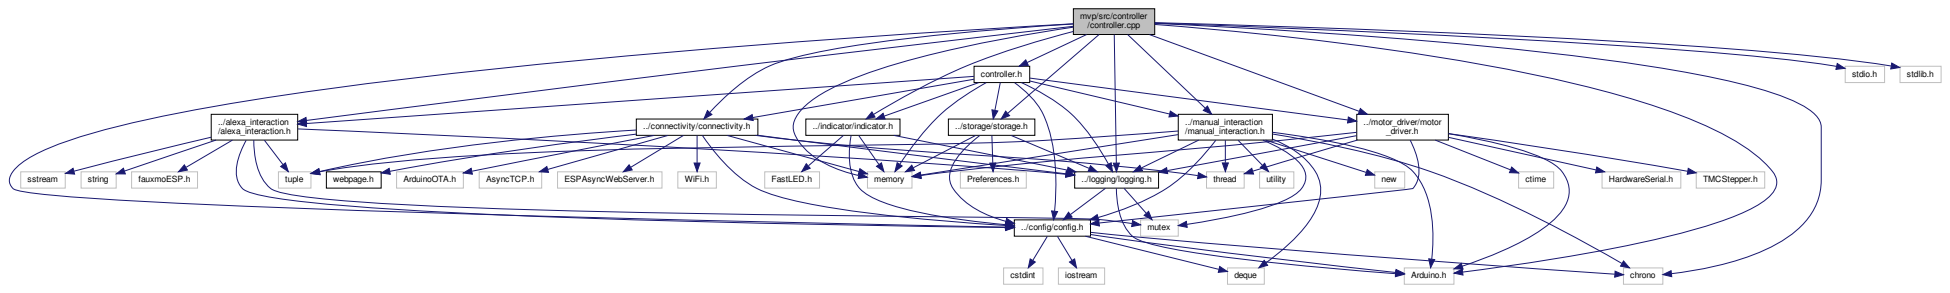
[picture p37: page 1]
controller.h; memory; ../alexa_interaction /alexa_interaction.h; ../config/config.h; Arduino.h; chrono; ../logging/logging.h; ../connectivity/connectivity.h; ../indicator/indicator.h; ../manual_interaction; /manual_interaction.h; ../motor_driver/motor _driver.h ../storage/storage.h; stdio.h; stdlib.h; mutex; sstream; string; fauxmoESP.h; tuple; cstdint; iostream; deque; webpage.h; ArduinoOTA.h; AsyncTCP.h; ESPAsyncWebServer.h; WiFi.h; FastLED.h; Preferences.h; thread; utility; new; ctime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

mvp/src/controller
/controller.cpp

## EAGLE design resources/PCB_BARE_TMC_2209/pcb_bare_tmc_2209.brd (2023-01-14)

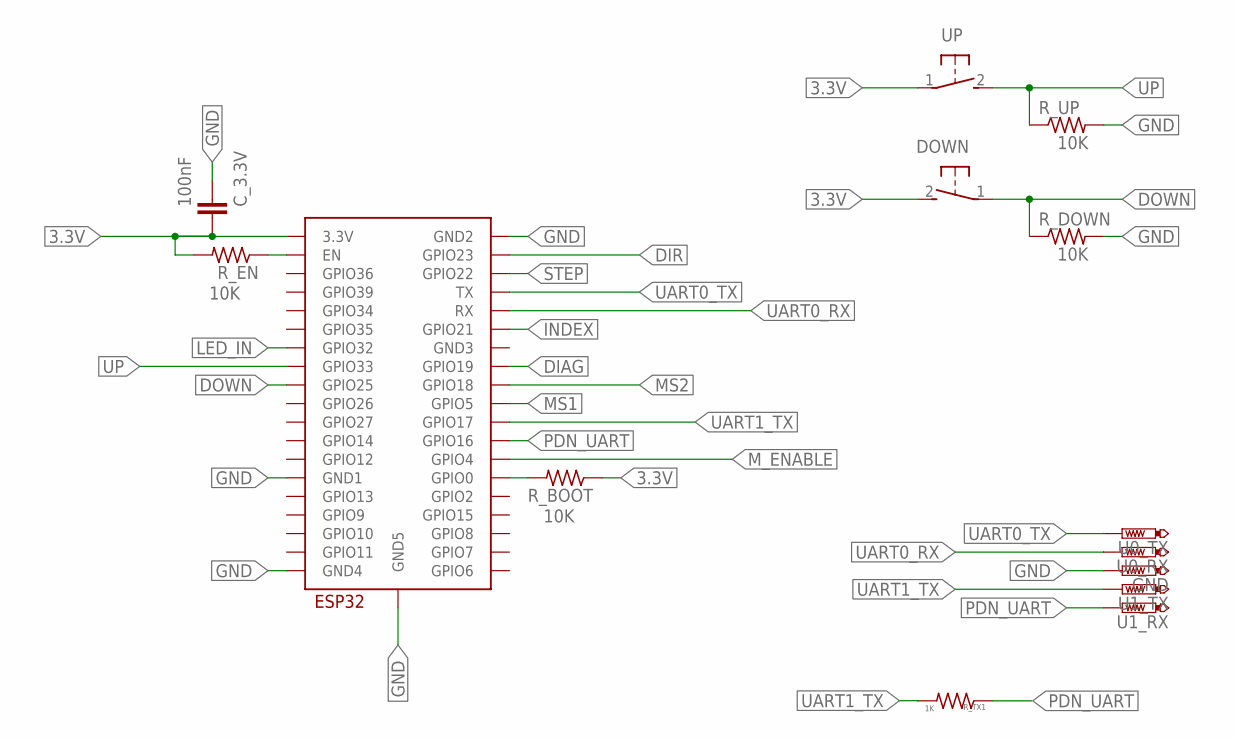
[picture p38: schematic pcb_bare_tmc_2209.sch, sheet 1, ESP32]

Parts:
C_3.3V: 100nF; C0805K
DOWN: 31-XX; B3F-31XX
GND: PTR1TP20SQ; TP20SQ
R_BOOT: 10K; R0805
R_DOWN: 10K; R0805
R_EN: 10K; R0805
R_TX1: 1K; R0805
R_UP: 10K; R0805
U0_RX, U0_TX, U1_RX, U1_TX: PTR1TP20SQ; TP20SQ
U$2: ESP32-WROOM
UP: 31-XX; B3F-31XX

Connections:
3.3V: C_3.3V.2, DOWN.2 (S), R_BOOT.1, R_EN.2, U$2.3V3 (3.3V), UP.1; also elsewhere on the board
DIAG: U$2.IO19 (GPIO19); also elsewhere on the board
DIR: U$2.IO23 (GPIO23); also elsewhere on the board
DOWN: DOWN.1, R_DOWN.1, U$2.IO25 (GPIO25)
GND: C_3.3V.1, GND.TP, R_DOWN.2, R_UP.2, U$2.GND1, U$2.GND2, U$2.GND4, U$2.GND5; also elsewhere on the board
INDEX: U$2.IO21 (GPIO21); also elsewhere on the board
LED_IN: U$2.IO32 (GPIO32); also elsewhere on the board
MS1: U$2.IO5 (GPIO5); also elsewhere on the board
MS2: U$2.IO18 (GPIO18); also elsewhere on the board
M_ENABLE: U$2.IO4 (GPIO4); also elsewhere on the board
unnamed: R_BOOT.2, U$2.IO0 (GPIO0)
unnamed: R_EN.1, U$2.EN
PDN_UART: R_TX1.1, U1_RX.TP, U$2.IO16 (GPIO16); also elsewhere on the board
STEP: U$2.IO22 (GPIO22); also elsewhere on the board
UART0_RX: U0_RX.TP, U$2.RX
UART0_TX: U0_TX.TP, U$2.TX
UART1_TX: R_TX1.2, U1_TX.TP, U$2.IO17 (GPIO17)
UP: R_UP.1, U$2.IO33 (GPIO33), UP.2 (S)

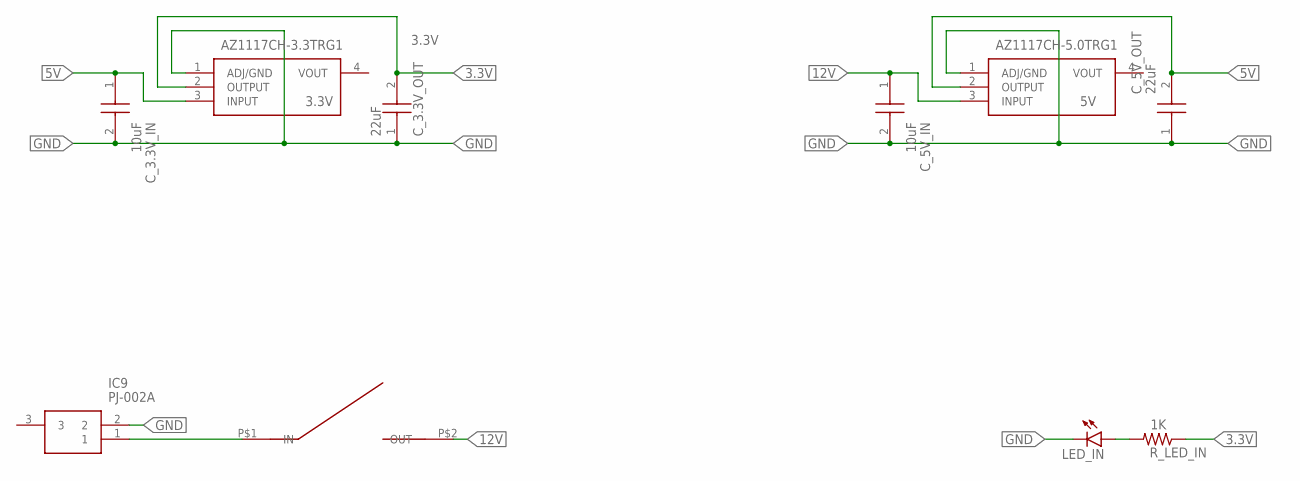
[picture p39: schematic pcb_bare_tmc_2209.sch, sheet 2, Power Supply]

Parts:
3.3V: AZ1117CH-3.3TRG1; SOT230P700X180-4N
5V: AZ1117CH-5.0TRG1; SOT230P700X180-4N
C_3.3V_IN, C_5V_IN: 10uF; CAPC2013X95N
C_3.3V_OUT, C_5V_OUT: 22uF; CAPC3216X100N
IC9: PJ-002A; PJ002A
LED_IN: LEDSML0805; SML0805
R_LED_IN: 1K; R0805
U$1: SPSTROCKERSWITCH2PIN; SPST2PINROCKER

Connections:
3.3V: 3.3V.2 (OUTPUT), C_3.3V_OUT.2, R_LED_IN.1; also elsewhere on the board
5V: 3.3V.3 (INPUT), 5V.2 (OUTPUT), C_3.3V_IN.1, C_5V_OUT.2; also elsewhere on the board
12V: 5V.3 (INPUT), C_5V_IN.1, U$1.P$2 (OUT); also elsewhere on the board
GND: 3.3V.1 (ADJ/GND), 5V.1 (ADJ/GND), C_3.3V_IN.2, C_3.3V_OUT.1, C_5V_IN.2, C_5V_OUT.1, IC9.2, LED_IN.C; also elsewhere on the board
unnamed: IC9.1, U$1.P$1 (IN)
unnamed: LED_IN.A, R_LED_IN.2

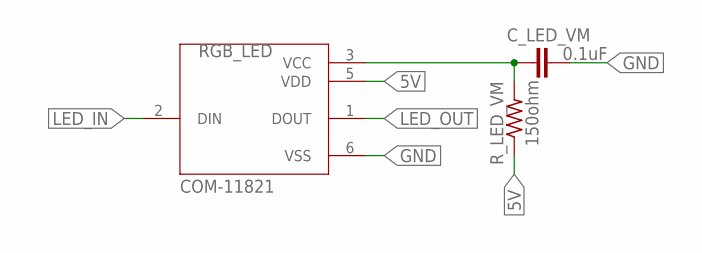
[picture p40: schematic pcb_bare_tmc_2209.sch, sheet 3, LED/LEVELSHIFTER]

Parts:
C_LED_VM: 0.1uF; C0805K
RGB_LED: COM-11821; LED_COM-11821
R_LED_VM: 150ohm; R0805

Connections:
5V: RGB_LED.5 (VDD), R_LED_VM.1; also elsewhere on the board
GND: C_LED_VM.2, RGB_LED.6 (VSS); also elsewhere on the board
LED_IN: RGB_LED.2 (DIN); also elsewhere on the board
LED_OUT: RGB_LED.1 (DOUT)
unnamed: C_LED_VM.1, RGB_LED.3 (VCC), R_LED_VM.2

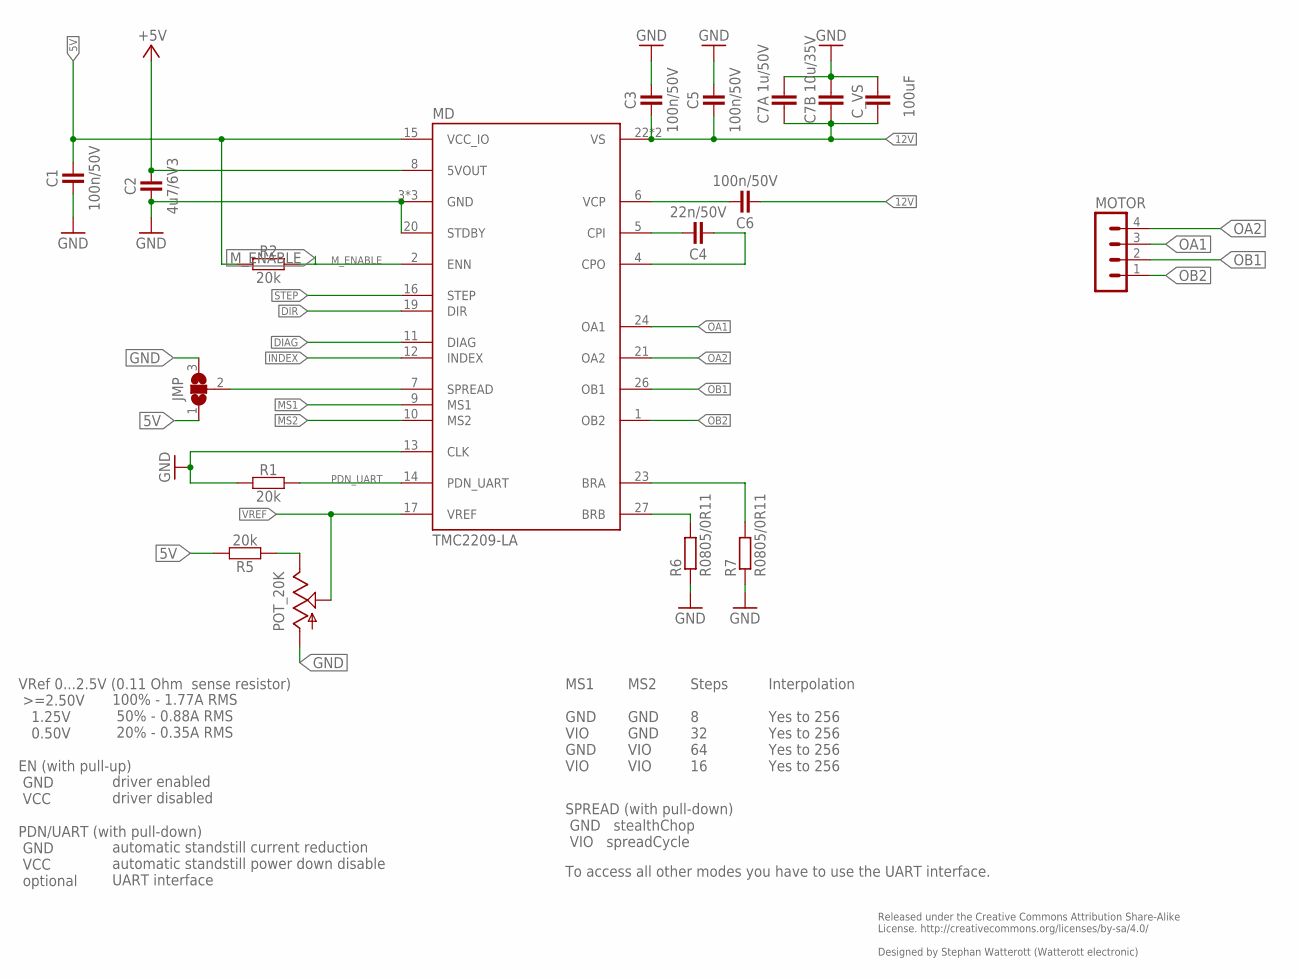
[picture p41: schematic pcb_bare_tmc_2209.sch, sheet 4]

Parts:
C1, C3, C5, C6: 100n/50V; C0402
C2: 4u7/6V3; C0402
C4: 22n/50V; C0402
C7A: 1u/50V; C0805
C7B: 10u/35V; C1206
C_VS: 100uF; C2.5-3
JMP: JUMPER3-0402-NC; JUMPER3-0402_NC
MD: TMC2209-LA; QFN28-PAD3.7
MOTOR: MA04-1
POT_20K: TRIM_US-3223G; 3223G
R1, R2, R5: 20k; C0402
R6, R7: R0805/0R11; M0805

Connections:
5V: C1.2, JMP.1, MD.15 (VCC_IO), R2.1, R5.2; also elsewhere on the board
12V: C3.1, C5.1, C6.1, C7A.1, C7B.1, C_VS.1, MD.22 (VS), MD.28 (VS); also elsewhere on the board
+5V: C2.2, MD.8 (5VOUT)
BRA: MD.23 (BRA), R7.2
BRB: MD.27 (BRB), R6.2
CPI: C4.2, MD.5 (CPI)
CPO: C4.1, MD.4 (CPO)
DIAG: MD.11 (DIAG); also elsewhere on the board
DIR: MD.19 (DIR); also elsewhere on the board
GND: C1.1, C2.1, C3.2, C5.2, C7A.2, C7B.2, C_VS.2, JMP.3, MD.3 (GND), MD.13 (CLK), MD.18 (GND), MD.20 (STDBY), MD.TP (GND), POT_20K.1 (A), R1.1, R6.1, R7.1; also elsewhere on the board
INDEX: MD.12 (INDEX); also elsewhere on the board
MS1: MD.9 (MS1); also elsewhere on the board
MS2: MD.10 (MS2); also elsewhere on the board
M_ENABLE: MD.2 (ENN), R2.2; also elsewhere on the board
unnamed: JMP.2, MD.7 (SPREAD)
OA1: MD.24 (OA1), MOTOR.3
OA2: MD.21 (OA2), MOTOR.4
OB1: MD.26 (OB1), MOTOR.2
OB2: MD.1 (OB2), MOTOR.1
PDN_UART: MD.14 (PDN_UART), R1.2; also elsewhere on the board
STEP: MD.16 (STEP); also elsewhere on the board
VCP: C6.2, MD.6 (VCP)
VREF: MD.17 (VREF), POT_20K.2 (S)
VREF1: POT_20K.3 (E), R5.1

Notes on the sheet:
Released under the Creative Commons Attribution Share-Alike License. http://creativecommons.org/licenses/by-sa/4.0/ Designed by Stephan Watterott (Watterott electronic)
VRef 0...2.5V (0.11 Ohm sense resistor) >=2.50V 1.25V 0.50V EN (with pull-up) GND VCC PDN/UART (with pull-down) GND VCC optional
100% - 1.77A RMS 50% - 0.88A RMS 20% - 0.35A RMS driver enabled driver disabled automatic standstill current reduction automatic standstill power down disable UART interface
MS1 GND VIO GND VIO
MS2 GND GND VIO VIO
Steps 8 32 64 16
Interpolation Yes to 256 Yes to 256 Yes to 256 Yes to 256
SPREAD (with pull-down) GND stealthChop VIO spreadCycle
To access all other modes you have to use the UART interface.

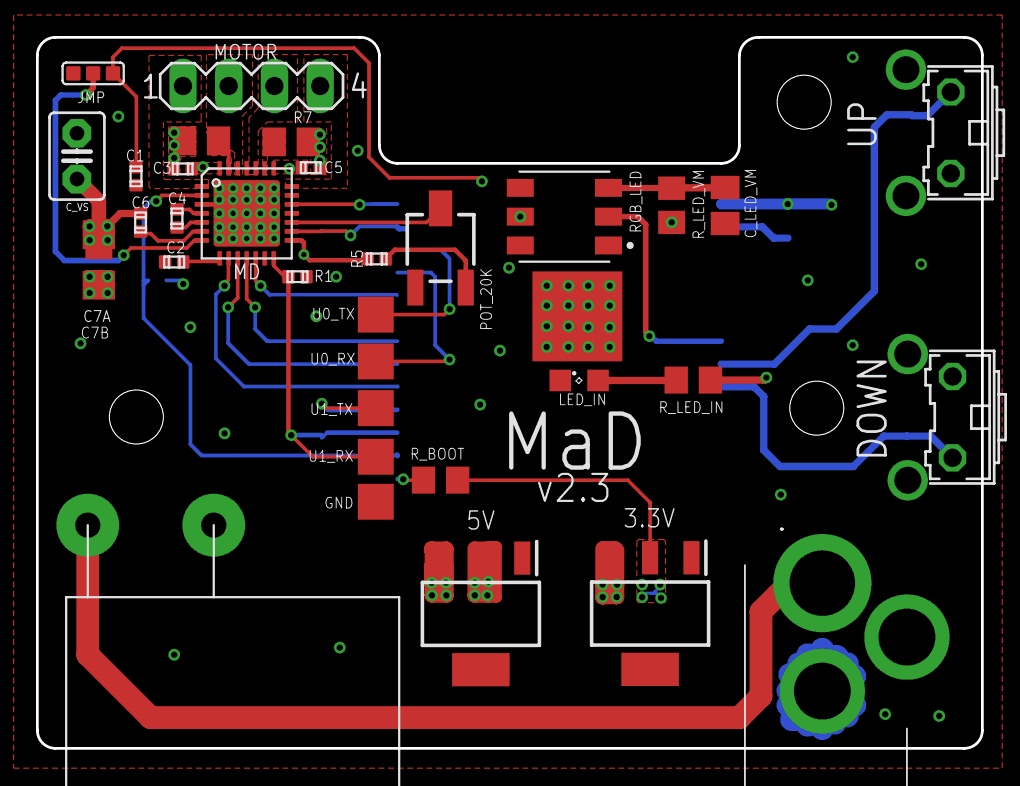
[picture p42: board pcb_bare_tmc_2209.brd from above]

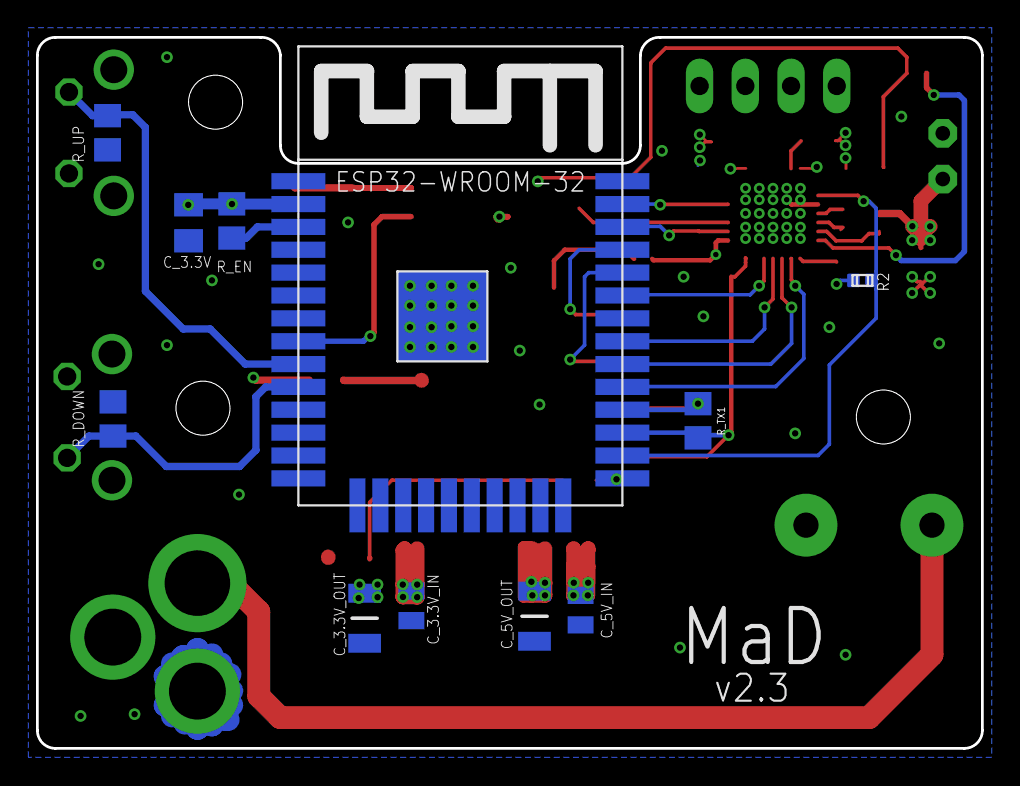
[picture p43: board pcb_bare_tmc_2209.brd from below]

Board: 4 copper layers, 52.5 x 39.5 mm, 45 parts (11 on the bottom side), 36 nets.

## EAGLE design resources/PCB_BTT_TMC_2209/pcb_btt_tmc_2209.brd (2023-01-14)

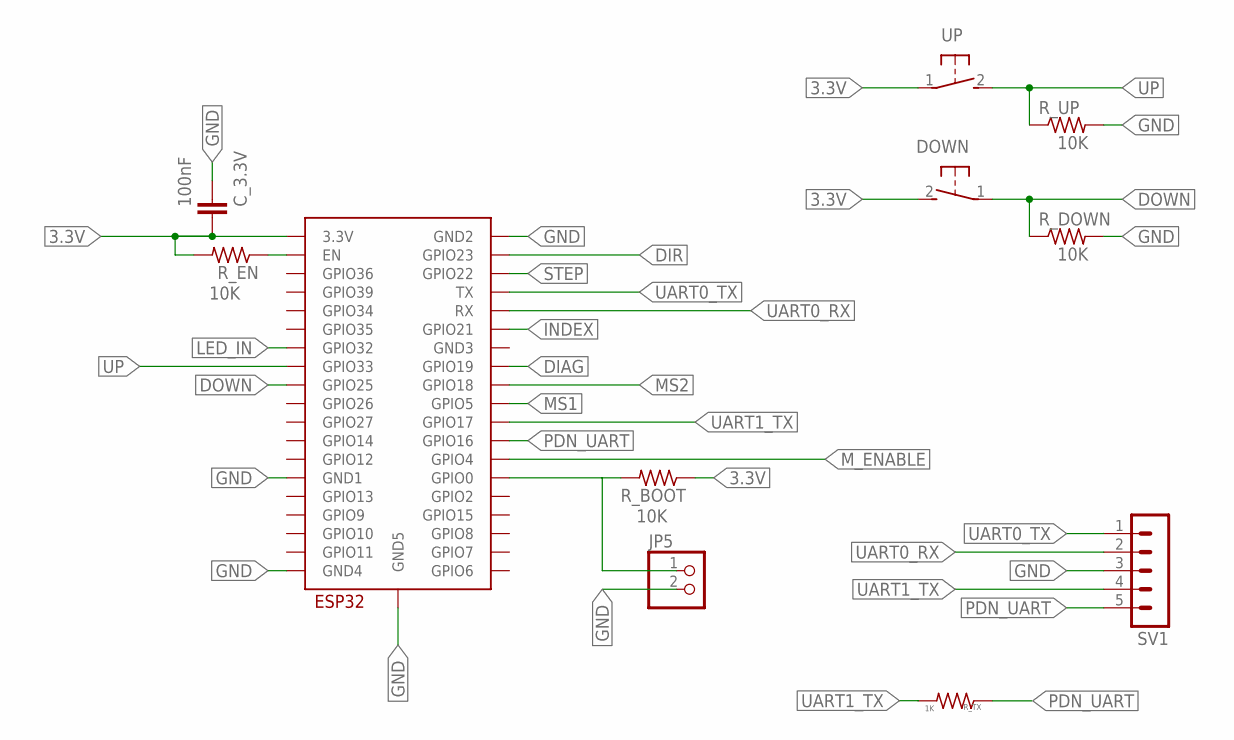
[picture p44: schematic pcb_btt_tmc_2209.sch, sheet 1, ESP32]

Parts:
C_3.3V: 100nF; C0805K
DOWN: 31-XX; B3F-31XX
JP5: PINHD-1X2; 1X02
R_BOOT: 10K; R0805
R_DOWN: 10K; R0805
R_EN: 10K; R0805
R_TX: 1K; R0805
R_UP: 10K; R0805
SV1: MA05-1
U$2: ESP32-WROOM
UP: 31-XX; B3F-31XX

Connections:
3.3V: C_3.3V.2, DOWN.2 (S), R_BOOT.1, R_EN.2, U$2.3V3 (3.3V), UP.1; also elsewhere on the board
DIAG: U$2.IO19 (GPIO19); also elsewhere on the board
DIR: U$2.IO23 (GPIO23); also elsewhere on the board
DOWN: DOWN.1, R_DOWN.1, U$2.IO25 (GPIO25)
GND: C_3.3V.1, JP5.2, R_DOWN.2, R_UP.2, SV1.3, U$2.GND1, U$2.GND2, U$2.GND4, U$2.GND5; also elsewhere on the board
INDEX: U$2.IO21 (GPIO21); also elsewhere on the board
LED_IN: U$2.IO32 (GPIO32); also elsewhere on the board
MS1: U$2.IO5 (GPIO5); also elsewhere on the board
MS2: U$2.IO18 (GPIO18); also elsewhere on the board
M_ENABLE: U$2.IO4 (GPIO4); also elsewhere on the board
unnamed: JP5.1, R_BOOT.2, U$2.IO0 (GPIO0)
unnamed: R_EN.1, U$2.EN
PDN_UART: R_TX.1, SV1.5, U$2.IO16 (GPIO16); also elsewhere on the board
STEP: U$2.IO22 (GPIO22); also elsewhere on the board
UART0_RX: SV1.2, U$2.RX
UART0_TX: SV1.1, U$2.TX
UART1_TX: R_TX.2, SV1.4, U$2.IO17 (GPIO17)
UP: R_UP.1, U$2.IO33 (GPIO33), UP.2 (S)

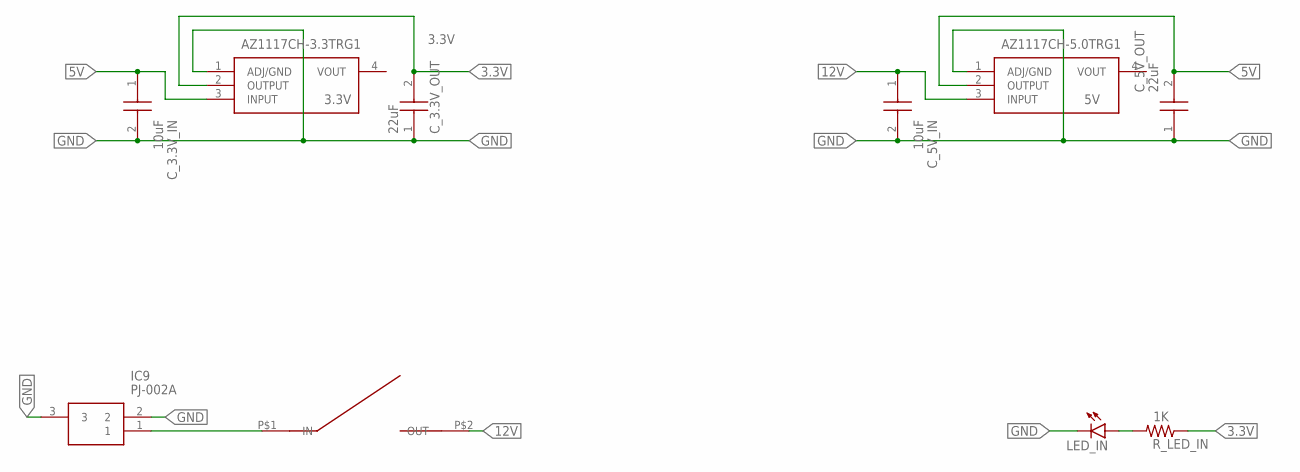
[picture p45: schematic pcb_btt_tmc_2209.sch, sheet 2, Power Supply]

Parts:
3.3V: AZ1117CH-3.3TRG1; SOT230P700X180-4N
5V: AZ1117CH-5.0TRG1; SOT230P700X180-4N
C_3.3V_IN, C_5V_IN: 10uF; CAPC2013X95N
C_3.3V_OUT, C_5V_OUT: 22uF; CAPC3216X100N
IC9: PJ-002A; PJ002A
LED_IN: LEDSML0805; SML0805
R_LED_IN: 1K; R0805
U$1: SPSTROCKERSWITCH2PIN; SPST2PINROCKER

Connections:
3.3V: 3.3V.2 (OUTPUT), C_3.3V_OUT.2, R_LED_IN.1; also elsewhere on the board
5V: 3.3V.3 (INPUT), 5V.2 (OUTPUT), C_3.3V_IN.1, C_5V_OUT.2; also elsewhere on the board
12V: 5V.3 (INPUT), C_5V_IN.1, U$1.P$2 (OUT); also elsewhere on the board
GND: 3.3V.1 (ADJ/GND), 5V.1 (ADJ/GND), C_3.3V_IN.2, C_3.3V_OUT.1, C_5V_IN.2, C_5V_OUT.1, IC9.2, IC9.3, LED_IN.C; also elsewhere on the board
unnamed: IC9.1, U$1.P$1 (IN)
unnamed: LED_IN.A, R_LED_IN.2

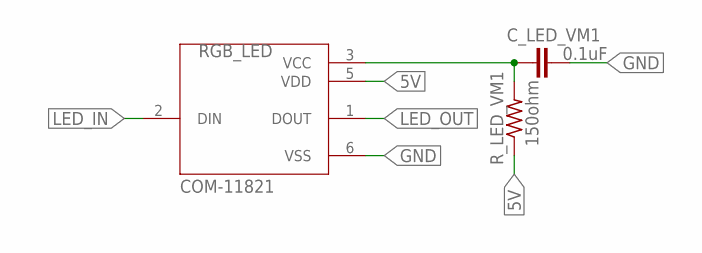
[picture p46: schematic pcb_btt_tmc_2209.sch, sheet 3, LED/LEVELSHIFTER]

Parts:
C_LED_VM1: 0.1uF; C0805K
RGB_LED: COM-11821; LED_COM-11821
R_LED_VM1: 150ohm; R0805

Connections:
5V: RGB_LED.5 (VDD), R_LED_VM1.1; also elsewhere on the board
GND: C_LED_VM1.2, RGB_LED.6 (VSS); also elsewhere on the board
LED_IN: RGB_LED.2 (DIN); also elsewhere on the board
LED_OUT: RGB_LED.1 (DOUT)
unnamed: C_LED_VM1.1, RGB_LED.3 (VCC), R_LED_VM1.2

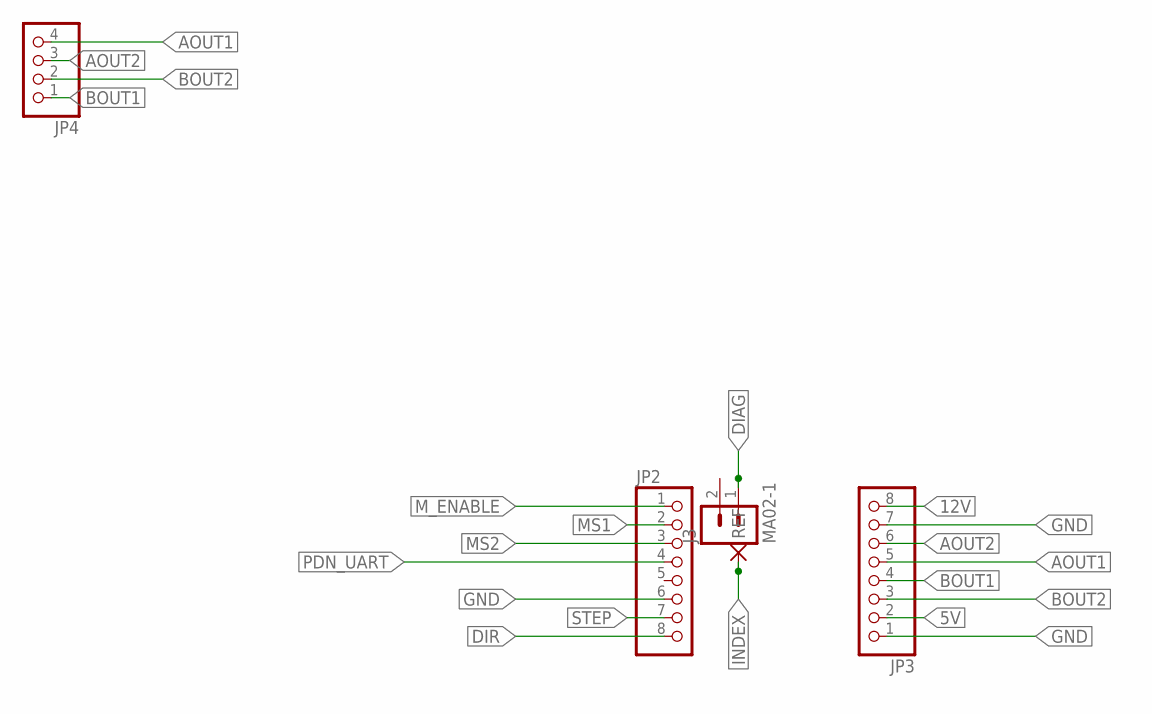
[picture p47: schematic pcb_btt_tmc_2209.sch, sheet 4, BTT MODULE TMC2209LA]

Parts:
J3: MA02-1
JP2, JP3: PINHD-1X8; 1X08
JP4: PINHD-1X4; 1X04
REF: PAD-0.6-1.1

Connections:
5V: JP3.2; also elsewhere on the board
12V: JP3.8; also elsewhere on the board
AOUT1: JP3.5, JP4.4
AOUT2: JP3.6, JP4.3
BOUT1: JP3.4, JP4.1
BOUT2: JP3.3, JP4.2
DIAG: J3.1; also elsewhere on the board
DIR: JP2.8; also elsewhere on the board
GND: JP2.6, JP3.1, JP3.7; also elsewhere on the board
INDEX: REF.1; also elsewhere on the board
MS1: JP2.2; also elsewhere on the board
MS2: JP2.3; also elsewhere on the board
M_ENABLE: JP2.1; also elsewhere on the board
PDN_UART: JP2.4; also elsewhere on the board
STEP: JP2.7; also elsewhere on the board

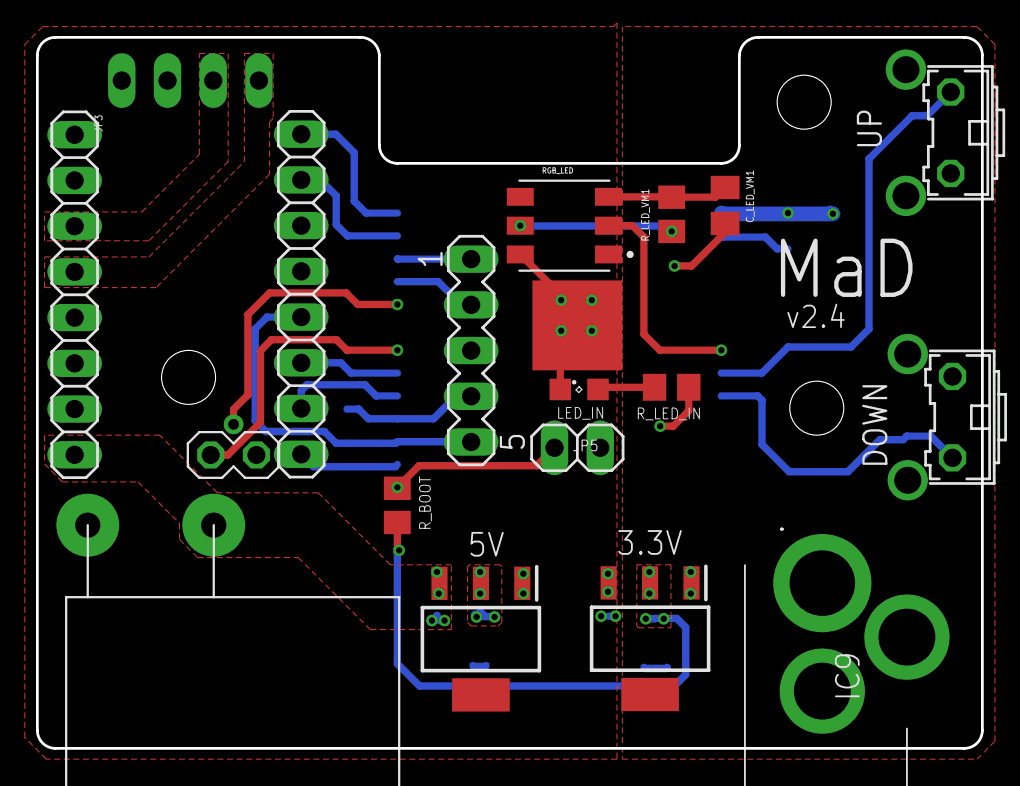
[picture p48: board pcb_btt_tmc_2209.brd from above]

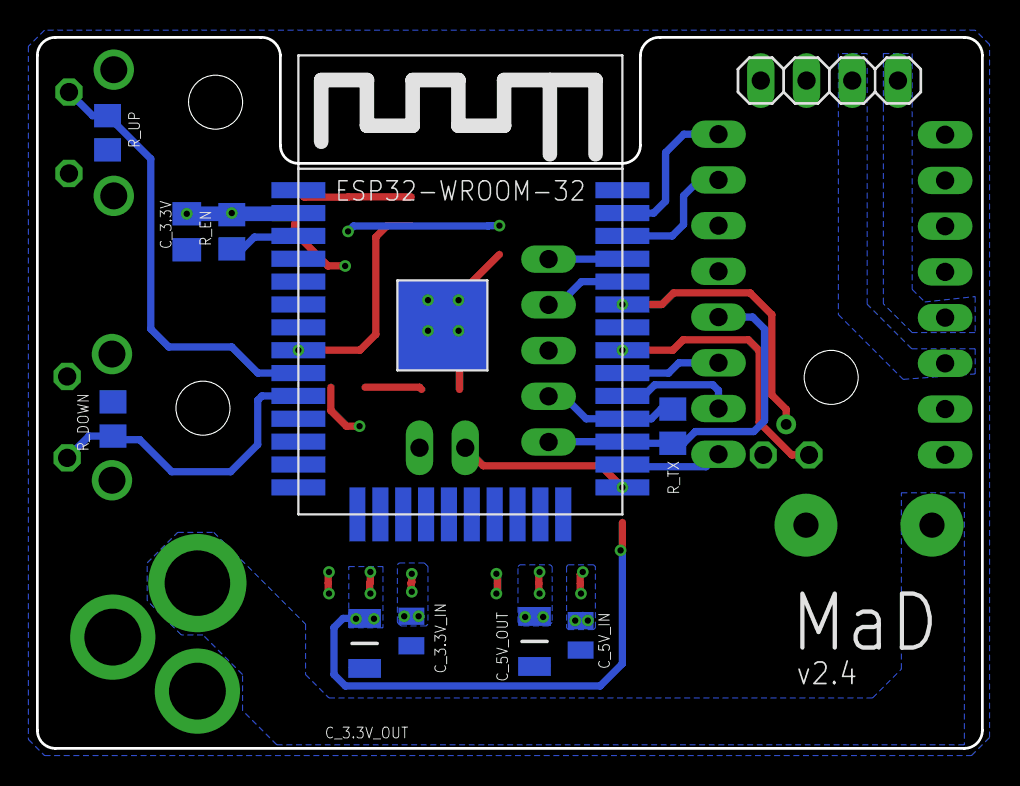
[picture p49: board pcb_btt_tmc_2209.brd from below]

Board: 2 copper layers, 52.5 x 39.5 mm, 29 parts (11 on the bottom side), 27 nets.

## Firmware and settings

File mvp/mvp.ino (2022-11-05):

/**
 * @file mvp.ino
 * @author Dhiraj Deshmukh (deshmukhdhiraj15@gmail.com)
 * @brief Arduino file for functioning automatic curtain
 * @version 0.1
 * @date 2022-07-19
 *
 * @copyright Copyright (c) 2022
 *
 */

#include <mutex>

#include "src/controller/controller.h"

std::unique_ptr<Controller> ctrl{nullptr};

/**
 * @brief Runs at the power on / device reset stage
 *
 */
void setup() {
    ctrl.reset(new Controller());
}

/**
 * @brief Runs recurrently until power on after setup, handles the device
 * functioning
 *
 */
void loop() {
    ctrl->Handle();
}

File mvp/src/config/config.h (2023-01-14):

/**
 * @file config.h
 * @author Mahimana Bhatt (mahimanabhatt@gmail.com)
 * @brief This header file contains all the constants and enum that will be used
 * throughout the repository like specific pins, mapping from state to led color
 * etc.
 * @version 0.1
 * @date 2022-07-19
 *
 * @copyright Copyright (c) 2022
 *
 */

#ifndef _CONFIG_INCLUDE_GUARD
#define _CONFIG_INCLUDE_GUARD

#include <Arduino.h>

#include <chrono>
#include <cstdint>
#include <deque>
#include <iostream>

/**
 * @brief Namespace to be used for constants/enums
 *
 */
namespace CONFIG_SET {

const int LOGGING_BAUD_RATE = 115200;
const int MOTOR_DRIVER_BAUD_RATE = 115200;
const int TRY_RECONNECT = 3;            // 3 seconds
const int MAX_SECONDS_LOST_WIFI = 600;  // 10 mins
const std::string STORAGE_NAMESPACE = "madac";

// Vars For Indicator Class
const int NUMBER_OF_LEDS = 1;
const int LED_BRIGHTNESS = 25;

// Freq var for Manual Interaction Class
const int DEQUE_ANALYZER_FREQ = 2;

/*
****** STORAGE KEYS ******
These keys are used by Storage class to retrieve the data from FLASHs
*/
const std::string KEY_SSID = "ssid";
const std::string KEY_PASSWORD = "password";
const std::string KEY_DEVICE_ID = "deviceID";
const std::string KEY_TOTAL_STEP_COUNT = "totalStepCount";
const std::string KEY_DIRECTION = "direction";
const std::string KEY_MODE = "mode";
const String DEFAULT_DEVICE_ID = "madac_blinds";

/*
****** MOTOR DRIVER CALIBRATION PARAMETERS ******
*/
const float MOTOR_DRIVER_R_SENSE = 0.11f;
const uint8_t MOTOR_DRIVER_ADDRESS = 0b00;
const uint8_t MOTOR_DRIVER_TOFF = 4;
const uint8_t MOTOR_DRIVER_BLANK_TIME = 24;
const uint16_t MOTOR_DRIVER_RMS_CURRENT = 2000;
const uint16_t MOTOR_DRIVER_MICROSTEP = 16;
const uint32_t MOTOR_DRIVER_TCOOL_THRS = 0xFFFFF;
const uint8_t MOTOR_DRIVER_SE_MIN = 0;
const uint8_t MOTOR_DRIVER_SE_MAX = 2;
const uint8_t MOTOR_DRIVER_SEDN = 0b01;
const uint32_t MOTOR_DRIVER_MAX_SPEED = 5000;
const int MOTOR_DRIVER_SG_THRESH = 45;
const int MOTOR_STOP_TIME_SEC = 120;                // 2 mins
const float STEP_FRACTION_ALLOWANCE = 0.05;         // 5% Allowance allowed for motor reaching destination
const int MODE_EXPIRE_TIME_LIMIT = 300;             // 5 mins
const int WIFI_DISCONNECT_RESTART_TIME_LIMIT = 60;  // 1 mins

enum class OPERATION_MODE {
    RESET,
    MAINTENANCE,
    USER,
    NA,
};

/*
****** ESP32 PINS ******
These are hardware ESP32 pin number where each external pin/component is
connected
PIN_RGB_LED     -> RGB LED WS2812
PIN_BUTTON_UP   -> Up button
PIN_BUTTON_DOWN -> Down button

Motor Driver (TMC2209) Pins
PIN_MD_ENABLE   -> Enable
PIN_MD_RX       -> Serial Receiver
PIN_MD_TX       -> Serial Transmitter
PIN_MD_MS1      -> MS1
PIN_MD_MS2      -> MS2
PIN_MD_STEP     -> Step
PIN_MD_DIR      -> Dir
PIN_MD_INDEX    -> Index
PIN_MD_DIAG     -> Diag (Stall)
*/
const int PIN_RGB_LED = 32;
static const int PIN_BUTTON_UP = 33;
static const int PIN_BUTTON_DOWN = 25;
const int PIN_MD_ENABLE = 4;
const int PIN_MD_RX = 16;
const int PIN_MD_TX = 17;
const int PIN_MD_MS1 = 5;
const int PIN_MD_MS2 = 18;
const int PIN_MD_STEP = 22;
const int PIN_MD_DIR = 23;
const int PIN_MD_INDEX = 21;
const int PIN_MD_DIAG = 19;

enum class LOG_TYPE {
    INFO,
    ERROR,
    WARN,
};

enum class LOG_CLASS {
    CONTROLLER,
    CONNECTIVITY,
    INDICATOR,
    LOGGING,
    MANUAL_INTERACTION,
    MOTOR_DRIVER,
    STORAGE,
    ALEXA_INTERACTION,
};

enum class MANUAL_PUSH {
    NO_PUSH,
    LONG_PRESS_UP,
    LONG_PRESS_DOWN,
    LONG_PRESS_BOTH,
    DOUBLE_TAP_UP,
    DOUBLE_TAP_DOWN,
    DOUBLE_TAP_BOTH,
};

enum class BUTTON_PRESS {
    NO_PUSH,
    LONG_PRESS,
    DOUBLE_TAP,
};

enum class DEVICE_STATUS {
    FAULT,
    OPERATION_MODE,
    RESET_MODE,
    MAINTENANCE_MODE,
};

enum class DRIVER_STATUS {
    AVAILABLE,
    BUSY,
    IN_ACTIVE,
};

struct MOTION_REQUEST {
    int PERCENTAGE;  // 0, 100 for blind traversal
};

struct DEVICE_CRED {
    String DEVICE_ID = "MaD Automatic Blinds";
    String SSID = "madac_blinds";
    String PASSWORD = "AutomaticCurtain";
};

struct CALIB_PARAMS {
    int TOTAL_STEP_COUNT = INT_MAX;
    bool DIRECTION = false;
};

// alias for time variables
using time_var = std::chrono::time_point<std::chrono::system_clock>;
using current_time = std::chrono::system_clock;

}  // namespace CONFIG_SET

#endif

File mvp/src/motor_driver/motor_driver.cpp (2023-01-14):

/**
 * @file motor_driver.cpp
 * @author Dhiraj Deshmukh (deshmukhdhiraj15@gmail.com)
 * @brief Contains algorithms for controlling stepper motor
 * @version 0.1
 * @date 2022-07-19
 *
 * @copyright Copyright (c) 2022
 *
 */

#include "motor_driver.h"

#include <Arduino.h>
#include <HardwareSerial.h>
#include <TMCStepper.h>

#include <ctime>

#include "../config/config.h"
#include "../logging/logging.h"

bool MotorDriver::direction_ = false;
int MotorDriver::current_step_ = 0;
int MotorDriver::full_rot_step_count_ = (4 * CONFIG_SET::MOTOR_DRIVER_MICROSTEP);

MotorDriver::MotorDriver(std::shared_ptr<Logging>& logging, CONFIG_SET::CALIB_PARAMS calib_param)
    : logger_(logging), TMC2209Stepper(&Serial2, CONFIG_SET::MOTOR_DRIVER_R_SENSE, CONFIG_SET::MOTOR_DRIVER_ADDRESS) {
    using namespace CONFIG_SET;
    pinMode(PIN_MD_DIAG, INPUT);
    pinMode(PIN_MD_ENABLE, OUTPUT);
    pinMode(PIN_MD_STEP, OUTPUT);
    pinMode(PIN_MD_DIR, OUTPUT);
    pinMode(PIN_MD_MS1, OUTPUT);
    pinMode(PIN_MD_MS2, OUTPUT);
    pinMode(PIN_MD_INDEX, INPUT_PULLUP);
    digitalWrite(PIN_MD_MS1, LOW);
    digitalWrite(PIN_MD_MS2, LOW);
    ResetSteps();

    Serial2.begin(MOTOR_DRIVER_BAUD_RATE, SERIAL_8N1, PIN_MD_RX, PIN_MD_TX);

    UpdateCalibParams(calib_param);
    attachInterrupt(PIN_MD_INDEX, MotorDriver::InterruptForIndex, RISING);
    StartHandler();
    logger_->Log(LOG_TYPE::INFO, LOG_CLASS::MOTOR_DRIVER, "Motor Driver Setup Completed");
}

MotorDriver::~MotorDriver() {
    EnableDriver(false);
    StopHandler();
}

bool MotorDriver::FulfillRequest(CONFIG_SET::MOTION_REQUEST request) {
    using namespace CONFIG_SET;
    if (is_motor_running_) {
        return false;
    }
    expected_step_ = (float(request.PERCENTAGE) / 100) * calib_params_.TOTAL_STEP_COUNT;
    // Handle 100, 0 for blinds traversals
    blind_traversal_requested_ = request.PERCENTAGE >= 100 || request.PERCENTAGE <= 0;
    if (blind_traversal_requested_) {
        direction_ = request.PERCENTAGE == 100;
    } else {
        direction_ = expected_step_ > current_step_;
    }
    logger_->Log(LOG_TYPE::INFO, LOG_CLASS::MOTOR_DRIVER, "Movement request received");
    return true;
}

CONFIG_SET::DRIVER_STATUS MotorDriver::GetStatus() {
    return (is_motor_running_) ? CONFIG_SET::DRIVER_STATUS::BUSY : CONFIG_SET::DRIVER_STATUS::AVAILABLE;
}

bool MotorDriver::EnableDriver(bool enable) {
    digitalWrite(CONFIG_SET::PIN_MD_ENABLE, !enable);
}

void MotorDriver::InitializeDriver() {
    using namespace CONFIG_SET;
    logger_->Log(LOG_TYPE::INFO, LOG_CLASS::MOTOR_DRIVER, "Initializing driver");
    this->begin();
    this->toff(MOTOR_DRIVER_TOFF);
    this->blank_time(MOTOR_DRIVER_BLANK_TIME);
    this->rms_current(MOTOR_DRIVER_RMS_CURRENT);
    this->microsteps(MOTOR_DRIVER_MICROSTEP);
    this->TCOOLTHRS(MOTOR_DRIVER_TCOOL_THRS);  // 20bit max
    this->semin(MOTOR_DRIVER_SE_MIN);
    this->semax(MOTOR_DRIVER_SE_MAX);
    this->shaft(false);
    this->sedn(MOTOR_DRIVER_SEDN);
    this->SGTHRS(MOTOR_DRIVER_SG_THRESH);
}

void MotorDriver::UpdateCalibParams(CONFIG_SET::CALIB_PARAMS calib_param) {
    calib_params_ = calib_param;
    EnableDriver(true);
    InitializeDriver();
    EnableDriver(false);
}

void MotorDriver::StopMotor() {
    using namespace CONFIG_SET;
    logger_->Log(LOG_TYPE::INFO, LOG_CLASS::MOTOR_DRIVER, "Stopping Motor");
    this->VACTUAL(0);
    EnableDriver(false);
    is_motor_running_ = false;
}

void MotorDriver::StartMotor() {
    using namespace CONFIG_SET;
    logger_->Log(LOG_TYPE::INFO, LOG_CLASS::MOTOR_DRIVER, "Starting Motor");
    EnableDriver(true);
    this->shaft(calib_params_.DIRECTION ^ direction_);
    this->VACTUAL(MOTOR_DRIVER_MAX_SPEED);
    is_motor_running_ = true;
    last_motor_start_time_sec_ = std::time(nullptr);
}

void IRAM_ATTR MotorDriver::InterruptForIndex() {
    current_step_ += (direction_) ? full_rot_step_count_ : -full_rot_step_count_;
}

bool MotorDriver::CancelCurrentRequest() {
    using namespace CONFIG_SET;
    logger_->Log(LOG_TYPE::INFO, LOG_CLASS::MOTOR_DRIVER, "Cancelling Request");
    stop_requested_ = is_motor_running_;
}

void MotorDriver::StopHandler() {
    keep_handler_running_ = false;
    handler_thread_->join();
}

void MotorDriver::StartHandler() {
    handler_thread_.reset(new std::thread(&MotorDriver::Handler, this));
}

void MotorDriver::Handler() {
    using namespace CONFIG_SET;
    logger_->Log(LOG_TYPE::INFO, LOG_CLASS::MOTOR_DRIVER, "Starting handler");
    keep_handler_running_ = true;

    while (keep_handler_running_) {
        using namespace CONFIG_SET;
        if (is_motor_running_) {
            bool current_step_out_of_bound = (current_step_ < 0) || (current_step_ > calib_params_.TOTAL_STEP_COUNT);
            if (current_step_out_of_bound) {
                current_step_ = (current_step_ < 0) ? 0 : calib_params_.TOTAL_STEP_COUNT;
            }

            bool reached_destination = false;
            bool step_in_limit = (current_step_ < (1 + STEP_FRACTION_ALLOWANCE) * expected_step_ &&
                                  (current_step_ > (1 - STEP_FRACTION_ALLOWANCE) * expected_step_));
            bool step_exceeded_bounds =
                (direction_ && current_step_ > (1 + STEP_FRACTION_ALLOWANCE) * expected_step_) ||
                (!direction_ && current_step_ < (1 - STEP_FRACTION_ALLOWANCE) * expected_step_);

            if (!blind_traversal_requested_ && (step_in_limit || step_exceeded_bounds)) {
                logger_->Log(LOG_TYPE::INFO, LOG_CLASS::MOTOR_DRIVER, "Reached Destination");
                reached_destination = !blind_traversal_requested_;
            }
            bool stall_detected = false;
            if ((std::time(nullptr) - last_motor_start_time_sec_) > 0.05) {
                stall_detected = digitalRead(PIN_MD_DIAG);
            }
            bool end_timer_reached = (std::time(nullptr) - last_motor_start_time_sec_) > MOTOR_STOP_TIME_SEC;
            if (stall_detected || reached_destination || end_timer_reached || stop_requested_) {
                StopMotor();
                expected_step_ = current_step_;
                stop_requested_ = false;
                blind_traversal_requested_ = false;
            }
        }
        if (!is_motor_running_ && (expected_step_ != current_step_ || blind_traversal_requested_)) {
            StartMotor();
        }
        std::this_thread::sleep_for(std::chrono::milliseconds(1));
    }
    logger_->Log(LOG_TYPE::INFO, LOG_CLASS::MOTOR_DRIVER, "Exiting handler");
}

int MotorDriver::GetSteps() {
    return current_step_;
}

void MotorDriver::ResetSteps() {
    current_step_ = 0;
}

int MotorDriver::GetPercentage() {
    return (float(current_step_) / calib_params_.TOTAL_STEP_COUNT) * 100;
}

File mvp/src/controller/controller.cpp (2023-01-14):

/**
 * @file controller.cpp
 * @author Dhiraj Deshmukh (deshmukhdhiraj15@gmail.com)
 * @brief Contains algorithms which controls the whole device from
 * initialization to giving commands to every subsystem
 * @version 0.1
 * @date 2022-07-19
 *
 * @copyright Copyright (c) 2022
 *
 */
#include "controller.h"

#include <Arduino.h>
#include <stdio.h>
#include <stdlib.h>

#include <chrono>
#include <memory>

#include "../alexa_interaction/alexa_interaction.h"
#include "../config/config.h"
#include "../connectivity/connectivity.h"
#include "../indicator/indicator.h"
#include "../logging/logging.h"
#include "../manual_interaction/manual_interaction.h"
#include "../motor_driver/motor_driver.h"
#include "../storage/storage.h"

Controller::Controller()
    : logger_(new Logging(true)),
      store_(new Storage(logger_)),
      indicator_(new Indicator(logger_)),
      manual_interaction_(new ManualInteraction(CONFIG_SET::DEQUE_ANALYZER_FREQ, logger_)),
      connectivity_{nullptr},
      motor_driver_{nullptr},
      alexa_interaction_{nullptr},
      long_press_enabled_(false),
      last_blind_percentage_(0),
      last_motor_status_(CONFIG_SET::DRIVER_STATUS::AVAILABLE) {
    using namespace CONFIG_SET;
    calib_params_ = CALIB_PARAMS();
    device_cred_ = DEVICE_CRED();
    store_->PopulateOperationMode(&operation_mode_);
    switch (operation_mode_) {
        case OPERATION_MODE::RESET:
            indicator_status_ = DEVICE_STATUS::RESET_MODE;
            InitializeResetMode();
            break;
        case OPERATION_MODE::MAINTENANCE:
            indicator_status_ = DEVICE_STATUS::MAINTENANCE_MODE;
            InitializeMaintenanceMode();
            break;
        case OPERATION_MODE::USER:
            indicator_status_ = DEVICE_STATUS::OPERATION_MODE;
            InitializeOperationMode();
            break;
        default:
            break;
    }
    logger_->Log(LOG_TYPE::INFO, LOG_CLASS::CONTROLLER, "Initialization Finished");
}

Controller::~Controller() {}

void Controller::Handle() {
    using namespace CONFIG_SET;
    indicator_->UpdateStatus(indicator_status_);
    switch (operation_mode_) {
        case OPERATION_MODE::RESET:
            HandleResetMode();
            break;
        case OPERATION_MODE::MAINTENANCE:
            HandleMaintenanceMode();
            break;
        case OPERATION_MODE::USER:
            HandleOperationMode();
            break;
        default:
            break;
    }
}

void Controller::InitializeResetMode() {
    using namespace CONFIG_SET;
    logger_->Log(LOG_TYPE::INFO, LOG_CLASS::CONTROLLER, "Starting Reset Mode");
    OPERATION_MODE op = OPERATION_MODE::USER;
    store_->SaveOperationMode(&op);
    connectivity_.reset(new Connectivity(logger_, &device_cred_));
    connectivity_->StartWebpage();
    mode_start_time_ = current_time::now();
}

void Controller::HandleResetMode() {
    using namespace CONFIG_SET;
    constexpr LOG_CLASS CONTROLLER = LOG_CLASS::CONTROLLER;
    constexpr LOG_TYPE INFO = LOG_TYPE::INFO;
    auto webpage_submission = connectivity_->GetWebpageSubmission();
    if (std::get<0>(webpage_submission)) {
        device_cred_ = std::get<1>(webpage_submission);
        logger_->Log(INFO, CONTROLLER, "Got the webpage submission");
        connectivity_->StopWebpage();
        connectivity_->StopWiFi();
        Calibrate();
        operation_mode_ = OPERATION_MODE::USER;
        store_->Clear();
        SaveParameters();
        RestartDevice();
    }
    MANUAL_PUSH manual_action_test;
    time_var manual_action_time_test;
    std::tie(manual_action_test, manual_action_time_test) = manual_interaction_->GetManualActionAndTime();
    if (manual_action_test == MANUAL_PUSH::DOUBLE_TAP_BOTH) {
        operation_mode_ = OPERATION_MODE::MAINTENANCE;
        indicator_status_ = DEVICE_STATUS::MAINTENANCE_MODE;
        StopResetMode();
        InitializeMaintenanceMode();
    }
    int exec_time = std::chrono::duration_cast<std::chrono::seconds>(current_time::now() - mode_start_time_).count();
    if (exec_time > MODE_EXPIRE_TIME_LIMIT) {
        // restarting
        logger_->Log(LOG_TYPE::INFO, LOG_CLASS::CONTROLLER, "Reset Mode Expired");
        RestartDevice();
    }
}

void Controller::InitializeMaintenanceMode() {
    using namespace CONFIG_SET;
    logger_->Log(LOG_TYPE::INFO, LOG_CLASS::CONTROLLER, "Starting Maintenance Mode");
    connectivity_.reset(new Connectivity(logger_, &device_cred_));
    connectivity_->StartOTA();
    mode_start_time_ = current_time::now();
}

void Controller::HandleMaintenanceMode() {
    using namespace CONFIG_SET;
    connectivity_->HandleOTA();
    int exec_time = std::chrono::duration_cast<std::chrono::seconds>(current_time::now() - mode_start_time_).count();
    if (exec_time > MODE_EXPIRE_TIME_LIMIT) {
        // restarting
        logger_->Log(LOG_TYPE::INFO, LOG_CLASS::CONTROLLER, "Maintenance Mode Expired");
        RestartDevice();
    }
}

void Controller::InitializeOperationMode() {
    using namespace CONFIG_SET;
    logger_->Log(LOG_TYPE::INFO, LOG_CLASS::CONTROLLER, "Starting Operation Mode");
    if (!LoadParameters()) {
        logger_->Log(LOG_TYPE::INFO, LOG_CLASS::CONTROLLER, "Storage Reading Failed.");
        indicator_status_ = DEVICE_STATUS::RESET_MODE;
        operation_mode_ = OPERATION_MODE::RESET;
        InitializeResetMode();
        return;
    }
    connectivity_.reset(new Connectivity(logger_, &device_cred_));
    connectivity_->StartEnsureConnectivity(device_cred_);
    delay(100);
    motor_driver_.reset(new MotorDriver(logger_, calib_params_));
}
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

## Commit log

2022-10-17 AC-131: Adding Final PCB Files
    [pcb_bare_tmc_2209.brd, pcb_bare_tmc_2209.sch, pcb_btt_tmc_2209.brd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]
2022-10-30 AC-129: Implement Motor Driver
2022-11-06 AC-146: Controller bugfix for starting motor for blind traversal
    [config.h, controller.cpp, motor_driver.cpp]
2022-11-11 Removing soft traversal, porting motor driver handler to separate thread
2022-11-11 Removing stall value from calibration params
    [config.h, controller.cpp, motor_driver.cpp]
2022-11-11 Removing reset driver function
    [motor_driver.cpp]
2022-11-11 Updating non stall detection
    [motor_driver.cpp]
2022-11-11 Started calibration implementation
2022-11-12 Calibration implemented
2022-11-12 Fixing number of steps calculation
    [controller.cpp, motor_driver.cpp]
2022-11-13 AC-151: Restart if in maintainence or reset mode for long time
    [config.h, controller.cpp]
2022-11-13 Updating reset mode start
    [config.h, controller.cpp]
2022-11-16 AC-154: Resolved MR comments, connectivity and controller updated. Set state Alexa
    [config.h, controller.cpp, motor_driver.cpp]
2023-01-14 AC-121: Implemented manual interaction, bugfixes and new features
    [config.h, controller.cpp]
2023-01-14 Including BOM for PCBs
2023-01-16 Final Mechanical Parts
    [P1_or_P2.STL]
